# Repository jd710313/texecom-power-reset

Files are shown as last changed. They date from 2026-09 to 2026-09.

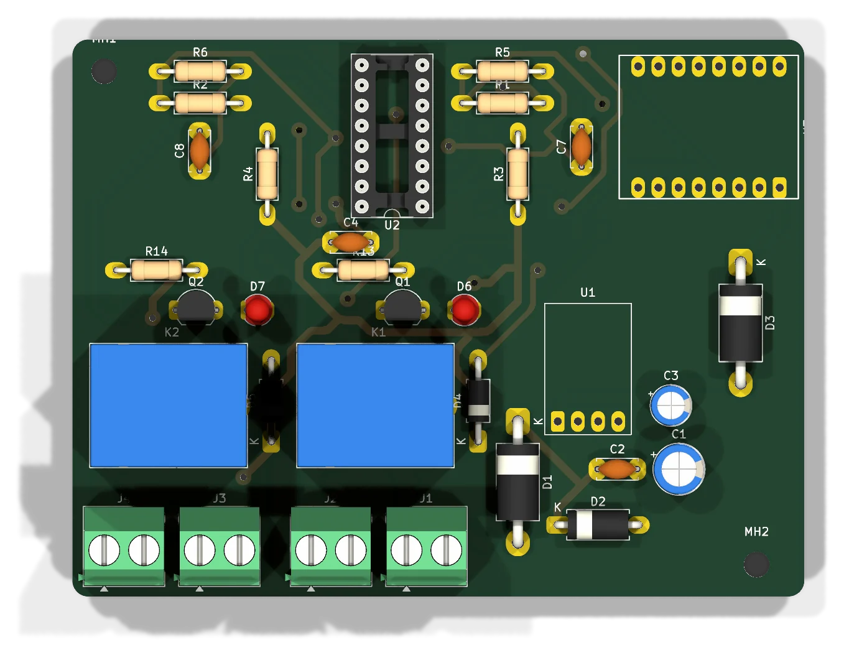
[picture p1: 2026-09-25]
docs/pcb-3d-top.webp

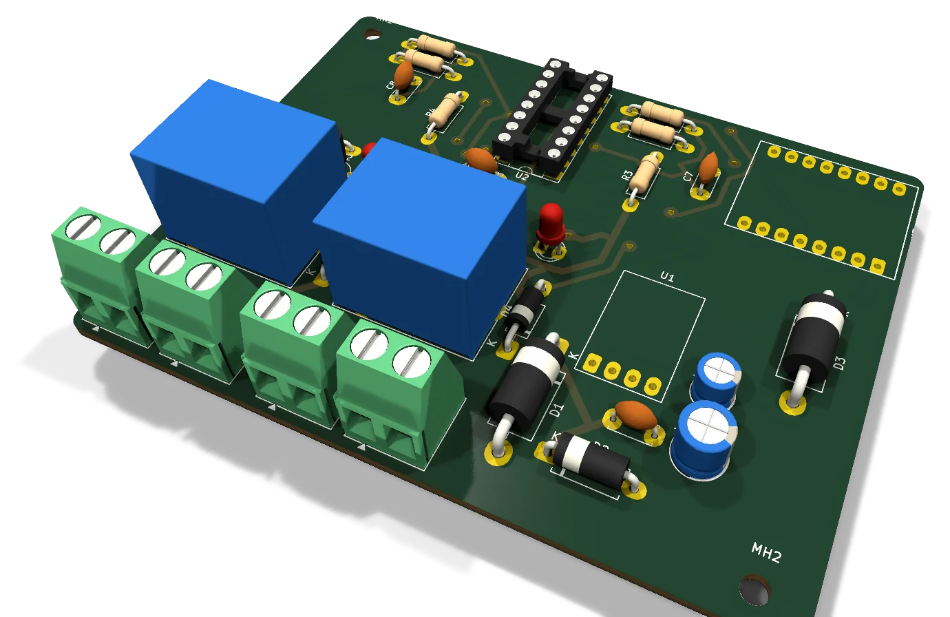
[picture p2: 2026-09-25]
docs/pcb-3d-angled.webp

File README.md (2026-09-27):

# Texecom Remote Power Reset

> **Project summary:** [`project-summary.html`](project-summary.html): one page with the
> reset timing, fail-safe behaviour, schematic, PCB layers, parts and bench tests.
> [View it rendered](https://htmlpreview.github.io/?https://github.com/jd710313/texecom-power-reset/blob/main/project-summary.html)
> (GitHub shows `.html` files as source), or download the file and open it in a browser.

A single board with an ESP32-C3 (Tasmota) and two on-board relays. It sits
inside a Texecom Premier Elite 64-W housing and can remotely "hard power
reset" the panel by briefly cutting both its battery and 16VAC feeds.

> **Status:** Design rev A with **on-board relays**. Schematic done (ERC clean,
> netlist verified). **PCB rev A routed: DRC clean (0 violations, 0 unconnected)**,
> GND pour on the bottom only, with an **engraved top legend** (`Mill_Legend`).
> Gerbers + drill + legend in `fab/`. Not yet milled or tested.

## Background

The panel occasionally raises an **"AUX 12V output failed"** fault. The only
way to clear it is to remove *all* power (battery and AC) and let the panel
restart. This board lets you do that remotely from Home Assistant.

The root cause (probably an overloaded or tripping AUX output) is being
investigated separately. This board is a remote recovery tool, not a fix.

## Requirements

### Panel

| # | Requirement |
|---|---|
| R1 | Panel: **Texecom Premier Elite 64-W** (built-in Ricochet wireless) |
| R2 | Firmware: **V6.05.03LS1** |
| R3 | Panel-side events after a reset (AC/battery fault logs, re-arming, etc.) are **out of scope**. They are handled manually. |
| R4 | AC presence and battery voltage are **already monitored** in Home Assistant through the Texecom integration, so this board doesn't monitor them. |

### Function

| # | Requirement |
|---|---|
| F1 | Remotely perform a "hard power reset" of the panel by cutting both the **battery 12V** feed and the **16VAC** feed at the same time. |
| F2 | Off duration: about **3 seconds** (Tasmota `PulseTime 30`). |
| F3 | Controlled from **Home Assistant over WiFi**, and reachable at all times. |
| F4 | The controller must **stay powered** while both panel feeds are cut. |

### Fail-safe

| # | Requirement |
|---|---|
| S1 | Panel feeds run through the relays' **NC (normally closed)** contacts. Coils are energised only during a reset, so a dead or unpowered board leaves the panel powered. |
| S2 | **Software timeout:** Tasmota `PulseTime`, so the relays release by themselves even if WiFi drops mid-reset. |
| S3 | **Hardware timeout:** a circuit between each GPIO and relay driver limits the maximum on-time (target about 5–10 s). This covers a firmware hang with the GPIO stuck high, and boot-time GPIO glitches. |

### Power

| # | Requirement |
|---|---|
| P1 | Powered from the **12V lead-acid battery only**, about 7.2Ah, tapped *before* the battery relay so it is never switched off. |
| P2 | The whole system is backed by **solar**, so no low-battery cutoff is needed. |
| P3 | Regulator: **Pololu S9V11E2F5** (5V buck-boost, 2–16V in, under 0.2mA quiescent). It supplies 5V to the ESP32-C3 SuperMini (5V pin), the 74HCT4538 and the relay coils. |
| P4 | Regulator input is **16V absolute max**. The battery floats at about 13.7V. The board adds **reverse-polarity protection**, a **bulk input capacitor** (≥33µF; 100µF used) and **transient protection**. |
| P5 | The battery tap on the board gets its **own small fuse** (about 0.5–1A, sized for the board's load). |
| P6 | Low power: Tasmota dynamic `Sleep` (WiFi stays connected). Target about 10–15mA average from the battery. |

### Hardware

| # | Requirement |
|---|---|
| H1 | MCU: **ESP32-C3 SuperMini**, socketed on female headers. |
| H2 | Relays: **2 × Songle SRD-05VDC-SL-C on the main PCB** ([Micro Robotics](https://www.robotics.org.za/SRD-5VDC-SL-C)). 5V coil (about 70mA each), contacts 10A at 30VDC / 250VAC, SPDT. Only COM and NC are used. |
| H3 | Each relay has a **transistor driver** (2N2222A), a **flyback diode** (1N4007) and a **red indicator LED** that lights while the coil is energised. |
| H4 | **Single board:** all field wiring lands on the PCB (battery in, battery out to the panel, 16VAC in, 16VAC out to the panel). There is no board-to-board wiring. |
| H5 | Screw terminals: **KF301-2P** (already on hand). 5.0mm pitch, 16A, 250V, 22–14 AWG, side entry, interlocking. Four are used (J1–J4). |
| H6 | **Custom PCB** (KiCad) holding the SuperMini socket, the S9V11E2F5, the 74HCT4538 hardware timeout, the relay drivers, both relays, the battery input protection and fuse, and J1–J4. |
| H7 | Everything must fit **inside the panel housing**. Rev A board is **92 × 70mm**; the relays are the tallest part (about 15.5mm). |
| H8 | The PCB is **CNC-milled in-house**, **double-sided** (FlatCAM with alignment pins, 30° V-bit with 0.1mm tip, 0.7mm tracks proven), from on-hand copper-clad board. There are **no plated through-holes, no solder mask and no silkscreen**. |

## Parts on hand

| Part | Source | Status in this design |
|---|---|---|
| ESP32-C3 SuperMini | n/a | U3 |
| KF301-2P screw terminals, 5mm (10-pack) | [Micro Robotics](https://www.robotics.org.za/KF301-2P) | J1–J4. **Suitable:** rated 16A / 250V, against about 1.6A max on the battery path and a 16VAC supply. |
| Capacitor kit (CAPKIT) | [Micro Robotics](https://www.robotics.org.za/CAPKIT) | C1 (100µF), C2/C4/C7/C8 (100nF), C3 (10µF) |
| Female and male headers, heat shrink, bootlace ferrules | n/a | SuperMini socket, Pololu header, wiring |
| REL-2CHAN-335V relay module | [Micro Robotics](https://www.robotics.org.za/REL-2CHAN-335V) | **No longer used** (replaced by on-board relays). Kept as a spare and for bench tests. |

## Wiring concept

```
                  ┌─────────────────────────── Main PCB ───────────────────────────┐
Battery +  ──► J1 BAT IN + ──┬──────────────────────────► K1 COM ─┐  NC            │
                             │                                    └──────► J2 BAT OUT + ──► Panel BATT +
                             └─ F1 → D1 → Pololu 5V → ESP32-C3, 74HCT4538, relay coils │
Battery −  ──► J1 BAT IN − ───── GND ─────────────────────────────────► J2 BAT OUT − ──► Panel BATT −
                                                                                       │
16VAC ~A   ──► J3 AC IN ~A ───────────────────────────► K2 COM ─┐  NC                  │
                                                                └──────► J4 AC OUT ~A ──► Panel AC ~A
16VAC ~B   ──► J3 AC IN ~B ───────────────────────────────────────────► J4 AC OUT ~B ──► Panel AC ~B
                  └────────────────────────────────────────────────────────────────┘
```

Each panel power path passes through **only two screw terminals** (in and out)
and one relay contact.

## Panel facts (Texecom INS176-15 installation manual)

From the *Premier Elite 12-W, 24-W & 48/64-W* sections:

| Item | Value |
|---|---|
| Battery fuse | **F6, 1.6A electronic PTC** |
| AUX 12V, Digicom, Network 1, Bell/Strobe fuses | 0.9A electronic PTC each |
| Panel current consumption | 150mA |
| Maximum current available | 1.0A, plus 0.3A battery charge (7Ah setting) |
| **Battery kick-start** | "The panel will only become live when the AC Mains is connected or the Battery Kick-start button is pressed." |
| Power-up order | Connect the battery first, then AC. |
| Troubleshooting | "Remove ALL power (AC Mains and Battery) and then reapply", which is the same procedure this board automates. |

**Relay rating check:** each relay path carries at most about 1.6A (the battery PTC
limit) or the panel's AC input current. The SRD-05VDC-SL-C contacts are rated
10A. **OK.**

**Kick-start consequence:** the panel only restarts after a reset if **AC is
present**. A reset during a real AC outage would leave the panel **off** until
someone presses the kick-start button. The Home Assistant script therefore
checks that AC is present before it resets (see below).

---

## Design: rev A (on-board relays)

### Block diagram

```
 Battery + ─J1─┬─ F1 PTC ─ D1 ─┬─ C1/C2/D2 ─ U1 Pololu ─► +5V ─┬─ D3 ─► SuperMini 5V
               │               │  bulk/TVS                   ├─► U2 74HCT4538 VCC
               │               │                             └─► relay coils, LEDs
               └───────────────┼──────────────► K1 COM ─ NC ─► J2 BAT OUT +
                               │
 GPIO4 ─ R9 1k ─┬─ reset ─┐                                          +5V
                └─ RC ────┴─► U2 ch1 (7 s max) ─ Q ─ R7 1k ─► Q1 2N2222A ─► K1 coil ┤ D4 flyback, D6 LED
 GPIO3 ─ R10 1k ─┬─ reset ─┐                                         +5V
                 └─ RC ────┴─► U2 ch2 (7 s max) ─ Q ─ R8 1k ─► Q2 2N2222A ─► K2 coil ┤ D5 flyback, D7 LED

 J3 AC IN ~A ─► K2 COM ─ NC ─► J4 AC OUT ~A        J3 ~B ─► J4 ~B (straight through)
```

### 1. Power input and protection

| Ref | Part | Purpose |
|-----|---|---|
| J1 | KF301-2P screw terminal | BAT IN (+/−). The power supply taps J1+ on the PCB, **before** the relay path, so it is never switched. |
| F1 | **Resettable PTC fuse**, 1206 SMD, 0.5A hold / 1A trip, 24V (Micro Robotics PTC05A24V) | Protects the board's battery branch (not the panel's battery path). The board draws about 0.25A peak at 12V. After a short, it trips, then resets by itself once the fault is removed. |
| D1 | 1N5822 Schottky (DO-201AD, 3A 40V), in series | Reverse-polarity protection (about 0.3V drop, negligible at about 15mA). |
| C1 | 100µF 35V radial electrolytic | Damps LC spikes from the battery leads, as Pololu recommends for the S9V11 (at least 33µF). |
| C2 | 100nF ceramic (radial, 5.08mm) | High-frequency decoupling. |
| D2 | P6KE18A TVS (DO-15) | Clamps larger transients. Its 15.3V standoff sits above the 13.8V float voltage, so no leakage. It is a last line of protection; C1 is the main LC-spike damper. |
| U1 | **Pololu S9V11E2F5** on a 1×4 header | 5V buck-boost, under 0.2mA quiescent. EN is left open (internal pull-up means always on). |
| C3 | 10µF 50V radial electrolytic | Output decoupling. |
| D3 | 1N5822 Schottky between +5V and SuperMini 5V | **Blocks USB backfeed.** The SuperMini's USB VBUS is tied straight to its 5V pin, so plugging in USB would otherwise push 5V from USB onto the relay coils and the Pololu output. The SuperMini still gets about 4.7V, which is fine for its 3.3V LDO. |

**Current budget (estimated):**

| State | 5V rail | From battery (at 13.6V, about 88% efficiency) |
|---|---|---|
| Idle, WiFi connected, Tasmota `Sleep` | about 25–35mA | **about 11–15mA** (0.3Ah/day, solar-backed) |
| Reset (both relays and LEDs on for 3 s) | about 150mA + ESP | about 90mA for 3 s |
| Worst-case peak (WiFi TX + relays) | about 0.5A | about 0.25A |

### 2. Controller: ESP32-C3 SuperMini

- Plugs into **two 1×8 female headers**, so it can be removed for flashing or
  replacement.
- Relay control pins: **GPIO4 → channel 1 (K1, battery)** and **GPIO3 →
  channel 2 (K2, AC)**. (Swapped from the first draft when the SuperMini
  footprint was corrected; this pairing keeps the tracks from crossing.)
  - Neither is a strapping pin (unlike GPIO2, 8 and 9), nor a USB pin (18, 19)
    or the UART0 pin that prints the boot log (GPIO21).
  - Both are plain inputs with **no internal pull-up at reset** (ESP32-C3
    datasheet, Table 2-1), so they can't pulse a relay while the ESP boots.
    GPIO6 (MTCK) and GPIO9 do have a weak pull-up at reset and are avoided.
- R1 and R2: **100k pull-downs** on the 74HCT4538 side of R9/R10. They hold the
  resets low (relays off) while the ESP is booting, unpowered or removed.
- R9 and R10: **1k series resistors** between each GPIO and the 74HCT4538.
  They protect the ESP when the 5V rail is off. See the note in §3.
- The V2 SuperMini's onboard LED is a **WS2812 RGB LED on GPIO8** (a strapping
  pin). It isn't used as a status LED; leave GPIO8 unassigned in Tasmota.
- **Orientation:** the module mounts **component (button) side up** with its
  **USB-C at the right-hand board edge** (engraved "USB →" on the legend), so it
  can be flashed in place. The antenna end therefore points into the board,
  about 8.5mm above the copper on the header sockets. If WiFi is weak inside the
  panel housing (especially a metal one), use the V2's **IPEX external-antenna
  option** (move the small antenna-select link as described on the module's
  info page) and fit the optional U.FL antenna from the BOM (Micro Robotics
  BAT-P60-WIFI-2, a stick-on flexible PCB antenna on a 100mm lead).

### 3. Hardware timeout: 74HCT4538 dual monostable (at 5V)

One chip (**TI CD74HCT4538E**, DIP-16) covers both channels. Each channel behaves as:

> **relay on = GPIO high AND less than T seconds since the GPIO went high**

| GPIO behaviour | Relay |
|---|---|
| Normal 3 s `PulseTime` pulse | On for 3 s (T is longer, so it never cuts a normal pulse short) |
| GPIO stuck **high** (firmware hang mid-reset) | Released after **T about 5–9 s (7 s nominal)**. It cannot re-trigger without a new low-to-high edge. |
| GPIO low or floating (crash, reboot, ESP removed) | Released immediately, because the reset input R is low |
| Short boot glitch high | Only as long as the glitch (µs), so the relay doesn't respond |
| 5V lost | 74HCT4538, drivers and relay coils all unpowered, relay released |

**Why a 74HCT at 5V (not a 74HC at 3.3V):** it runs from the same 5V rail as the
relay drivers, and it gives a full 5V drive to the transistor bases. HCT inputs
use TTL thresholds (**high = 2.0V or above**, low = 0.8V or below), so the ESP's
3.3V GPIO drives them reliably. (It was chosen originally when bench test 1b
showed the relay *module's* input needed 4.77mA; with on-board relays the choice
still stands.)

**Wiring for each channel.** TI pin names are used here; Nexperia's datasheet
swaps the letters A and B, but the **pin numbers and functions are identical**.

| CD74HCT4538 pin (ch1 / ch2) | Connection |
|---|---|
| R 3 / 13 (active-low reset) | Node N: GPIO through **R9/R10 1k**, with **R1/R2 100k** pull-down to GND at the chip side |
| A 4 / 12 (leading-edge / rising trigger) | Node N through **R5/R6 10k**, with **C7/C8 100nF** to GND. The 1ms delay makes sure reset is released **before** the trigger edge arrives. The Schmitt input handles the slow edge. |
| B 5 / 11 (trailing-edge trigger) | Tied to **VCC** (TI: "an unused B should be tied to VCC") |
| CX 1 / 15 | GND |
| RXCX 2 / 14 | REXT **R3/R4 1M** to +5V. CEXT **C5/C6 10µF X5R 1206** to GND through **R11/R12 100Ω** in series (TI's rapid power-down protection, Fig. 13). |
| Q 6 / 10 | Relay driver: **R7/R8 1k** to the Q1/Q2 base (§3a) |
| Q̅ 7 / 9 | Not used |
| VCC 16 | +5V, with **C4 100nF** decoupling |
| GND 8 | GND |

**Timing:** T = 0.7 × REXT × CEXT = 0.7 × 1M × 10µF ≈ **7 s nominal** (TI
datasheet: τ = 0.7·RX·CX, RX min 5k; noise susceptibility "may occur for
RX > 1M", so 1M is the upper limit). It needs to stay above 3.5 s (the longest
`PulseTime`) and, ideally, below 30 s. **Bench test 3** confirms the real value.
Tune it by lowering REXT or changing CEXT. Keep the RXCX traces short.

- **CEXT must be low-leakage.** With REXT at 1M the timing current is only about
  5µA, so an aluminium electrolytic (leakage in the µA range) would upset the
  timing badly. Use an **X7R/X5R ceramic**. Avoid **Y5V** ceramics, which can
  lose 50–80% of their capacitance.
- **Power-down protection:** TI requires protection when CX is 0.5µF or more.
  The 100Ω in series with CX limits the discharge current into pins 2/14 if 5V
  collapses quickly.
- **Use 74HCT4538** (TI CD74HCT4538E from Communica). A 74HC4538 won't reliably
  read 3.3V inputs at 5V, and a CD4538 has too little output drive.

**ESP protection (does 5V reach the ESP?):** no. The ESP pins only drive the
74HCT4538's **inputs**, which are high-impedance CMOS gates. No 5V output
connects to any ESP pin, so the ESP never sees more than its own 3.3V.

The one corner case is the **5V rail being off while the ESP is powered**, for
example on USB for flashing (D3 blocks USB from the 5V rail). If the ESP then
drives a GPIO high, current could flow through the chip's input clamp diode into
the unpowered 5V rail. **R9/R10 (1k)** limit that to under 3mA, which is harmless
for both parts. They cost nothing in normal operation, because the HCT inputs
draw no current.

### 3a. Relay drivers and relays

| Ref (ch1 / ch2) | Part | Purpose |
|---|---|---|
| R7 / R8 | 1k, 1206 | Base resistor: (5V − 0.75V) / 1k ≈ **4.3mA** base current, within the 74HCT4538's 4mA-class output rating |
| R13 / R14 | 10k, ¼W | Base pull-down: keeps the transistor off if U2 is unpowered or removed from its socket |
| Q1 / Q2 | **2N2222A**, TO-92 | Low-side coil switch. Coil current about 72mA; forced gain about 17, so the transistor is fully saturated. |
| K1 / K2 | **SRD-05VDC-SL-C** | K1 switches the battery (J1 → COM, NC → J2); K2 switches 16VAC ~A (J3 → COM, NC → J4). NO contacts unused. |
| D4 / D5 | **1N4007** | Flyback diode across each coil (cathode to +5V) |
| R15 / R16 + D6 / D7 | 1k, 1206 + **red 3mm LED** | Across each coil: lights (about 3mA) while that relay is energised, that is while the panel feed is **cut** |

**Relay pin-out (KiCad Relay_SPDT_SANYOU_SRD_Series_Form_C, matches the Songle SRD):**
1 = COM, 4 = NC, 3 = NO, 2 and 5 = coil.

**2N2222A pin-out warning:** TO-92 2N2222A parts are usually **E-B-C**, but
some makers use other orders. The footprint is TO-92 inline with pin 1 = E,
2 = B, 3 = C. **Check the pin-out of the actual transistors** before soldering.

**Fail-safe chain:** GPIO low / ESP dead → U2 reset low → Q low → R13/R14 hold
the base low → coil off → **NC closed** → panel powered. U2 unpowered or pulled
from its socket gives the same result.

### 4. Connectors

**Screw terminals:** all **KF301-2P** (5.0mm pitch, 16A / 250V, 22–14 AWG).

| Ref | Label (engraved) | Pin 1 | Pin 2 | Wires to |
|-----|---|---|---|---|
| J1 | BAT IN | + | − | Battery |
| J2 | BAT OUT | + | − | Panel BATT terminals |
| J3 | AC IN | ~A | ~B | 16VAC supply |
| J4 | AC OUT | ~A | ~B | Panel AC terminals |

### 5. Field wiring

| From | To |
|---|-----|
| Battery + / − | J1 BAT IN + / − |
| J2 BAT OUT + / − | Panel BATT + / − (the panel's original battery leads) |
| 16VAC supply ~A / ~B | J3 AC IN ~A / ~B |
| J4 AC OUT ~A / ~B | Panel AC terminals |

**Wire:** 0.5–0.75mm² (20–18 AWG) for the battery and AC runs, with ferrules in
the screw terminals.

**Recommended:** an in-line fuse (about 3A) on the battery + lead, close to
the battery. The battery current now runs through the PCB, and a 7Ah SLA
battery can deliver very high currents into a short before the panel's own F6
PTC (which sits downstream) can do anything.

### 6. PCB

- 2-layer, **about 70 × 50mm** (estimated): two relays (19 × 15.5mm each) in,
  and the relay module, J5, J6, J7 and the control lead out. The housing
  dimensions are still open.
- **Placement:** J1–J4 along one edge with K1/K2 right behind them, so the
  battery and AC paths are short. The SuperMini sits at the opposite edge,
  as far from the relays as possible, with its USB-C at the board edge.
- **Heavy-current traces** (J1 → K1 → J2, J3 → K2 → J4, and the BAT− and AC ~B
  straight-throughs): at least **2mm wide** on 1oz copper (about 3A at
  10°C rise), or copper pours.
- **Clearance:** the 16VAC lines swing about ±23V relative to GND (the
  panel's bridge rectifier references them to 0V). Keep at least 1mm from logic
  traces. This is low voltage, so no mains-level creepage is needed.
- **Footprint pitch:** the KF301 is 5.0mm. Use a 5.0mm footprint (not 5.08mm)
  so that interlocked blocks line up.
- **Through-hole wherever possible:** axial resistors and diodes, radial
  capacitors, TO-92, DIP-16 in a socket, 2.54mm headers. **1206 SMD is
  acceptable** (hand-solderable) and is used for F1, C5/C6 and several resistors.
- GND pour on the **bottom layer only**. The top
  layer carries only tracks, pads and the engraved legend (§6a).
- 2 × M3 mounting holes.

### 6a. CNC-milling rules (H8)

**Process:** KiCad → Gerbers + Excellon drill → **FlatCAM** (isolation and drill
G-code) → CNC. **Double-sided**, with FlatCAM flip alignment using **alignment
pins**. Tool: **30° V-bit, 0.1mm tip**. The machine has milled 0.7mm tracks
reliably (see the example board), and all common drill sizes are available.

Milled boards have **no plated through-holes, no solder mask and no
silkscreen**, so the layout follows these rules:

| Rule | Why |
|---|-----|
| **Double-sided, but a top-layer connection is only allowed on pads that can be soldered on top.** Axial resistors and diodes, and radial capacitors and LEDs mounted slightly raised, can be soldered on top. The IC socket, female headers, male header under the Pololu, relays, TO-92 transistors (usually) and KF301 terminals **cannot**, because their bodies cover the top pads. | There's no plating to carry a top trace to a bottom joint. |
| **Enforced in KiCad:** the footprints of the covered parts get **bottom-copper-only pads**, so neither manual routing nor the autorouter can connect to them on top. | Makes the rule impossible to break by accident, including by the autorouter. |
| **Vias** are drilled and fitted with a **wire link soldered on both sides.** Keep them few (target 10 or fewer), with 0.8mm drill and 2.0mm pads. **0Ω links** (RES-0E-50) can also serve as crossings. | Every via is a manual solder job. |
| **1206 SMD parts go on the bottom side.** | They're soldered on the same side as the through-hole joints. |
| **Traces 0.7mm by default** (proven on this machine; 0.6mm minimum where needed), **clearance at least 0.4mm**. Power paths at least 2mm, and 16VAC traces at least 1mm from logic. | Proven geometry for the 30°/0.1mm V-bit |
| **Oval, oversized pads** (for example 2.0 × 3.0mm for 0.8–1.0mm holes, bigger for terminals, relays and the 1N5822s). | User's standard practice for easy hand soldering |
| **Extra clearance around pads:** a custom KiCad rule of **at least 0.8mm from any pad to other copper** (tracks at 0.4mm to each other), plus **component spacing** that keeps neighbouring pads and bodies well clear. | The user prefers wider isolation around pads for easy hand soldering and no solder bridges. FlatCAM's multi-pass isolation needs room to widen the cut around pads without eating into neighbouring traces. |
| **Drill sizes:** 0.8mm (resistors, small capacitors, LEDs, TO-92, vias), 1.0mm (headers, IC socket, 1N4007, 0Ω links), 1.3–1.5mm (KF301, relay pins, 1N5822 at 1.3mm leads, C1), 3.2mm (M3 mounting holes). | Few tool changes |
| **GND pour on the bottom only.** The top layer has no pour; its unused copper stays as floating copper and carries the engraved legend. | Faster milling and good grounding on the bottom. A top pour would reach pads that can't be soldered on top, and it would leave nowhere to engrave the legend. |
| **SuperMini USB-C at the board edge** (antenna end inward). | Flashing in place, and it let the corrected footprint keep the proven routing. Use the V2's external-antenna option if WiFi is weak. |
| **Legend engraved into the top copper** from the `Mill_Legend` layer (User.1): part outlines, polarity and pin-1 marks, references, the terminal labels BAT IN / BAT OUT / AC IN / AC OUT with + / − on the battery terminals, and a small **ring beside every pad that must be soldered on top** (key: "○ = SOLDER TOP"). The rings are placed so each one is clearly nearest its own pad. Generated so every line stays **at least 0.35mm clear of any top copper feature or hole** (plus half the line width), so an engrave can never cut a track or pad. | No silkscreen. The legend shows where each part goes. |
| After testing, **coat the board** (conformal coat or clear lacquer). | No solder mask, and the board lives in the panel for years. |

**Routing:** I place the parts and then try routing. If that's poor, use the
user's preferred autorouter, the **KiCad routing tools (Go implementation)**, with
the rules above as design rules.

### 6b. KiCad project

| File | Contents |
|---|---|
| `texecom-power-reset.kicad_pro` / `.kicad_sch` | Project and schematic (A3, single sheet). **Drawn with wires**; only GND, +5V and +5V_MCU use power symbols or labels. |
| `texecom-power-reset-schematic.pdf` | Schematic PDF export |
| `texecom-power-reset.kicad_sym` | Project symbols: ESP32-C3-SuperMini (from the esp32c3-button-led project), Pololu_S9V11E2F5 |
| `texecom-power-reset.pretty/` | Project footprints: ESP32-C3-SuperMini (**pin rows corrected 2026-09-25**: the first version was mirrored, which would have put 5V and GND on GPIO5/GPIO6 with the module button side up), Pololu_S9V11E2x (pin order VOUT, GND, VIN, EN per the Pololu drawing) |
| `backup/` | Earlier schematic versions (label-connected, and wired with the off-board relay module), kept for reference only. **Not** used for the PCB. |
| `project-summary.html` | One-page visual project summary (self-contained HTML, open in a browser) |
| `fab/` | **Reference export** (maintained with the design): Gerbers F.Cu / B.Cu / Edge.Cuts / Mill_Legend, Excellon drill, drill map |
| `kicad-output/` | Working KiCad output folder used for milling (Gerbers, drill and anything else needed) |
| `flatcam/` | FlatCAM work: project files and generated G-code |
| `docs/` | Copper renders (top includes the legend), 3D renders, and the **top and bottom assembly drawings** (`pcb-assembly-top` / `pcb-assembly-bottom`, SVG + PDF) |
| `tools/make_legend.py` | Regenerates the `Mill_Legend` engrave layer, kept clear of all top copper |
| `tools/make_assembly.py` | Regenerates the top and bottom assembly drawings (SVG + PDF) from the board |

**Layout:** power path across the top. **Channel 2** (GPIO3, K2 AC relay) is in
the middle band and **channel 1** (GPIO4, K1 battery relay) in the lower band.
This order avoids wire crossings from the SuperMini. J3/J4 (AC) sit next to K2,
and J2 (BAT OUT) next to K1. The BAT_IN+ wire runs from J1 over the top and down
the right side to K1 COM.

**Reference designators** match BOM.md: U1 Pololu, U2 74HCT4538 (units A/B =
channels 1/2, unit C = power), U3 SuperMini, J1–J4 KF301 terminals, K1/K2
relays, Q1/Q2 2N2222A, F1 PTC, D1/D3 1N5822, D2 P6KE18A, D4/D5 1N4007,
D6/D7 LEDs, C1–C8, R1–R16, MH1/MH2 M3 holes.

**Verification:** ERC 0 errors, 0 warnings. The KiCad netlist was checked net
by net against the intended circuit (32 nets). The only unconnected pins are the
intentional ones (relay NO, Q̅ outputs, Pololu EN, unused SuperMini pins).

### 6c. PCB layout (rev A)

Top copper
Bottom copper

| Item | Value |
|---|---|
| Board | **92 × 70mm**, 2 layers, 2 × M3 holes (top-left, bottom-right) |
| Placement | Terminals along the bottom edge: **J4 AC OUT, J3 AC IN, J2 BAT OUT, J1 BAT IN** (left to right). K2 (AC) above J4/J3, K1 (battery) above J2/J1. Drivers and LEDs above the relays, 74HCT4538 top-middle, SuperMini top-right (button side up, **USB-C at the right-hand edge**, antenna end pointing inward), power section bottom-right. |
| Routing | KiCad routing tools (drandyhaas), with a milling floor: **0.8mm clearance** everywhere (1.0mm for 16VAC), 0.7mm signal tracks, 1.0mm supply tracks, 2.0mm battery/AC tracks. GND by a **bottom-layer pour only**, plus a few GND tracks. |
| Vias | **16 wire-link vias** (0.8mm drill, 2.0mm pad): solder a short wire on both sides. |
| Legend | `Mill_Legend` layer (User.1), engraved into the top copper with the V-bit. See *Engraving the legend* below. |
| DRC | **0 violations, 0 unconnected** against the project rules (`.kicad_pro` net classes + `.kicad_dru`). |
| Fab files | `fab/`: `texecom-power-reset-F_Cu.gbr`, `-B_Cu.gbr`, `-Edge_Cuts.gbr`, `-Mill_Legend.gbr` (legend engrave), `texecom-power-reset.drl` (Excellon, mm, absolute origin; PTH and NPTH merged), drill map PDF. |

**Drill sizes:**

| Drill | Holes | Used for |
|---|---|---|
| 0.8mm | 66 | Resistors, disc caps, electrolytics, TO-92, DIP socket, the 16 vias |
| 0.9mm | 4 | LEDs |
| 1.0mm | 30 | SuperMini and Pololu headers, 1N4007/P6KE18A, relay coil pins |
| 1.3mm | 14 | KF301 terminals, relay contact pins |
| 1.5mm | 4 | 1N5822 (1.3mm leads) |
| 3.2mm | 2 | M3 mounting holes |

**How the "no top joint on covered pads" rule is enforced** (so the router can't
create a connection that can't be soldered):

- KiCad forces plated pads onto both copper layers, so the covered footprints
  (terminals, relays, DIP socket, headers, TO-92, electrolytics, LEDs) carry a
  **per-pad F.Cu keepout** (no tracks, no vias, no pour) inside the footprint.
  These are in the `*_Mill` footprints in `texecom-power-reset.pretty/`.
- There is **no top pour** at all. The `.kicad_dru` rule **"no top pour on
  covered pads"** (`zone_connection none` on F.Cu) is kept as a guard in case a
  top pour is ever added again. DRC connectivity is therefore honest: every
  connection it counts is solderable.

**Assembly notes for the milled board:**

Two assembly drawings, both printable at 2:1 on A4 landscape (print at 100%).
The vias carry the same numbers on both.

- **Top side** ([PDF](docs/pcb-assembly-top.pdf)): every top-side part with
  its reference and value, its outline with polarity and pin-1 marks, and the
  20 pads that need a top solder joint ringed in orange (the same pads as the
  rings on the engraved legend).
- **Bottom side** ([PDF](docs/pcb-assembly-bottom.pdf)): there's no silkscreen
  on the bottom, so this shows the board as seen from below (mirrored), with the
  eleven 1206 parts labelled and all 16 vias numbered. The through-hole parts
  appear in grey for orientation.

Top-side assembly drawing

Bottom-side assembly drawing

1. **Vias:** fit a wire through each of the 16 vias and solder both sides first.
2. **SMD (1206) parts are on the bottom** (F1, C5, C6, R7–R12, R15, R16): solder
   them first, on the bottom.
3. **Axial parts and disc capacitors** (R1–R6, R13, R14, D1–D5, C2, C4, C7, C8):
   mount them **1–2mm off the board** so the iron can reach the top pads, and
   **solder every pad on both sides**. The holes aren't plated, so the top and
   bottom pads are only joined by solder on the lead. Twenty of these pads carry
   a top track, and for those the top joint is **essential** (some have no
   bottom track at all). They're marked on the board with a small engraved
   **ring (○ = SOLDER TOP)** next to the pad. Soldering the other top pads is
   harmless and keeps the rule simple.

   | Part | Type | Pads with a top track | Net |
   |------|------|-----------------------|-----|
   | R1 | Axial resistor | 1, 2 | U2A reset, GND |
   | R2 | Axial resistor | 1 | U2B reset |
   | R3 | Axial resistor | 1 | +5V |
   | R4 | Axial resistor | 1 | +5V |
   | R5 | Axial resistor | 1, 2 | U2A reset, U2A trigger |
   | R6 | Axial resistor | 1, 2 | U2B reset, U2B trigger |
   | R13 | Axial resistor | none | |
   | R14 | Axial resistor | 2 | GND |
   | D1 | Axial diode (1N5822) | 1 | D1 cathode |
   | D2 | Axial diode (P6KE18A) | 1 | D1 cathode |
   | D3 | Axial diode (1N5822) | none | |
   | D4 | Axial diode (1N4007) | 1, 2 | +5V, D4 anode |
   | D5 | Axial diode (1N4007) | 1 | +5V |
   | C2 | Disc capacitor | 1 | D1 cathode |
   | C4 | Disc capacitor | 1, 2 | +5V, GND |
   | C7 | Disc capacitor | 1 | U2A trigger |
   | C8 | Disc capacitor | 1 | U2B trigger |

   Solder the top joint first, then the bottom. Afterwards, check continuity
   from each ringed pad to the far end of its top track.
4. **Everything else** (terminals, relays, socket, headers, TO-92s, electrolytics,
   LEDs) is soldered on the **bottom only**; their top pads are isolated rings.
   - **SuperMini (U3):** solder male pins to the module and two 1×8 female
     headers to the board (bottom side). Plug the module in **button side up,
     USB-C towards the right-hand board edge**, following the engraved
     "USB →" arrow. Before plugging it in, check that the square pad (pin 1,
     5V) is at the USB end of the row nearest the relays.
5. After testing, coat the board (no solder mask).

**Milling order (double-sided, alignment pins, height map):**

1. **Alignment-pin holes** first, outside the board outline, so the pins are
   ready for the flip.
2. **Bottom side:** probe a height map (no holes yet, so the probe can't drop
   into one), then mill the **B.Cu isolation, mirrored** around the pin axis
   (**4 passes**, see *Isolation passes* below).
3. **Flip** onto the alignment pins and probe a **new height map on the top**
   (the top face isn't flat in the same way as the bottom).
4. **Top isolation** (F.Cu, not mirrored, **4 passes**).
5. **Legend** (Mill_Legend, not mirrored) with the same V-bit, Z zero and
   height map; see below.
6. **Drill from the top** (drill file not mirrored), with a firm sacrificial
   backing so exit burrs on the bottom pads stay small. Re-zero Z after each
   drill change (the height map isn't needed for drilling through). Mill the
   3.2mm M3 holes as circles if you don't have a 3.2mm drill.
7. **Board outline last** (2.4mm tool, 4 passes to −2.0mm, no tabs). The board
   is held on **double-sided tape**, so it stays put after the final pass; tape
   near the edges as well as the middle. The drills go through the tape, so
   clean adhesive off the small bits if holes start to come out ragged.
8. Lightly deburr the bottom pads before soldering.

**Isolation passes (copper layers): use 4, not 1**

The first board was milled with **one pass** of the V-bit (about 0.14mm wide at
−0.07mm). Isolation routing cuts a line **around the outline** of each copper
shape; it doesn't clear the space *between* shapes. With one pass:

- **Top:** there's no pour, so every pad and track sits in unused, floating
  copper only about 0.14mm away. Solder can bridge a pad to that copper, and if
  the same piece touches another pad, you get a short.
- **Bottom:** the Gerber has 0.8mm gaps between tracks, pads and the GND pour.
  One pass traces *both edges* of each gap: narrow gaps get cleared completely
  (the cuts merge), wider or irregular ones (for example around thermal-relief
  spokes) keep a **sliver of copper** between the two cuts. That's why the
  separation looked wide in some places and thin in others.

Settings for both copper layers (FlatCAM Beta, Isolation tool):

| Setting | Value |
|---|---|
| Passes | **4** |
| Overlap | **15–20%** |
| Combine | On (all passes in one job) |
| Tool, depth, height map | Unchanged (30° V-bit, 0.1mm tip, −0.07mm, auto-level) |

That gives about 0.45–0.5mm of isolation from every copper edge: the 0.8mm
bottom gaps are cleared completely (no slivers, even look), and the top pads get
about 0.5mm to the floating copper. The **legend stays a single Follow pass**.
FlatCAM's Non-Copper Clearing would remove all unused copper, but with a 0.1mm
V-bit it's very slow; the extra passes give the clearance that matters.

**Checking a milled board:** under magnification, scrape out any copper slivers
with a sharp hobby knife and brush the dust away. Then check with a continuity
meter for shorts between neighbouring pads, and from each pad to the copper
around it, especially the terminal, relay and 5V pads, before soldering.

**Alignment holes with a 2.4mm fishtail end mill (at 12,000rpm):**

| Setting | Value | Why |
|---|---|---|
| Z (plunge) feed | **100–150mm/min** (no more than about 200) | About 0.0125mm/rev, or 0.006mm per flute on a 2-flute bit: enough to cut chips in FR4. The earlier 60mm/min tends to rub, which heats the resin, glazes the hole and dulls the bit. A fishtail isn't a drill (no point, no self-centring), and hobby machines flex under heavier plunges. |
| Step-down | **1mm per step**, full retract between steps (−1, −2, −3mm) | Clears the fibreglass dust; 3mm total is a 1.6mm board plus about 1.4mm into the spoilboard for the pins. |
| Dust | Vacuum while drilling | Fibreglass dust packs into the flutes. |

- **Pin fit:** a flat-bottomed end-mill hole comes out very close to the bit
  size. If the pins are also 2.4mm, test on scrap first. If they're too tight,
  use a slightly smaller pin, or mill the holes (FlatCAM "mill holes") for a snug
  sliding fit.
- **First hole:** if the bit squeals or the resin turns brown, increase the feed
  a little rather than slowing down.
- These are general carbide-in-FR4 figures for hobby spindles; if the bit's
  supplier lists feeds, use those.

**Hole drills at 12,000rpm (carbide PCB drills in FR4):**

| Drill | Holes | Z (plunge) feed |
|---|---|---|
| 0.8mm | 66 | **60–90mm/min** |
| 1.0mm (includes the 0.9mm LED holes) | 34 | **80–120mm/min** |
| 1.5mm (includes the 1.3mm terminal and relay-contact holes) | 18 | **100–150mm/min** |
| 3.2mm (M3) | 2 | **120–180mm/min** |

- PCB drills are designed for 30,000–100,000rpm. At 12,000rpm each turn must
  take a smaller bite, or thin bits break, so the feed scales with the diameter
  (about 0.005–0.015mm per revolution).
- A single plunge to −2.0mm (no pecking) is fine for a 1.6mm board at these
  sizes. Set **Feedrate Z per tool** in FlatCAM's drilling job and regenerate the
  drill G-code.
- The **0.8mm bit is the fragile one**: keep it at the low end, make sure it
  runs true, and clean tape adhesive off it. On the larger bits, if a bit
  squeals or the hole edges go brown, raise the feed a step rather than slowing
  down.
- These are general figures for hobby spindles; if the drill supplier lists
  feeds, use those.

**Engraving the legend (FlatCAM):**

The legend Gerber is made of 0.15mm-wide lines. Normal isolation routing would
cut *around* each line (a double outline); **Follow** geometry runs the tool
once down the **centre** of each line, so the V-bit cuts a single thin groove.

1. Load `fab/texecom-power-reset-Mill_Legend.gbr` together with the F.Cu
   Gerber. It shares their origin, so it lines up with the top isolation and
   the alignment pins. Apply **exactly the same** offset or double-sided
   move/mirror to the legend as to F.Cu (select both and apply it once).
2. Make the Follow geometry:
   - **FlatCAM Beta (8.99x):** select the legend Gerber, open the **Isolation
     Routing** tool and tick **Follow**. Tool diameter and passes don't matter
     with Follow. Generate: this creates a `…_follow` geometry.
   - **FlatCAM 8.5:** select the legend Gerber; in the Selected tab under
     *Isolation Routing* tick **Follow**, then *Generate Geometry*.
   - Check the result: text, outlines and rings should be single centre
     lines, not pairs of outlines.
3. CNC job on the follow geometry: tool type **V-shape, 0.1mm tip, 30°**,
   **Cut Z about −0.05 to −0.07mm** (just through 35µm copper, giving a line
   about 0.12–0.14mm wide), **multi-depth off**. Use the feeds, speed and
   travel Z from the top isolation job. A deeper cut widens the lines and blurs
   the small text (1.2mm references, 1.5mm terminal labels), so try a short
   test on scrap first.
4. The cut is very shallow, so **use the top height map** (auto-levelling);
   without it, lines fade out on high spots and cut wide on low ones.
5. The legend was generated at least 0.35mm clear of everything on the top
   copper, so even a slightly deep cut only marks floating (unconnected) copper.
   If you change the layout, regenerate it with `tools/make_legend.py` (run with
   KiCad's Python; see the script header) rather than editing it by hand.

FlatCAM menu names differ a little between versions.

### 7. Tasmota configuration

Build: `tasmota32c3.bin` (flash through the SuperMini's USB-C, with the board
unpowered from the battery; D3 isolates USB from the relay rail).

`Configuration → Configure Module` (Generic ESP32-C3):

| GPIO | Function |
|---|---|
| GPIO4 | Relay 1 (battery, K1) |
| GPIO3 | Relay 2 (AC, K2) |
| GPIO8 | None (WS2812 RGB LED and strapping pin; leave unassigned) |

Console:

```
Backlog PowerOnState 0; PulseTime1 30; PulseTime2 35; Sleep 100; FriendlyName1 Panel Battery Cut; FriendlyName2 Panel AC Cut
```

| Setting | Why |
|---|-----|
| `PowerOnState 0` | Relays are **always off** after an ESP reboot or power-up. |
| `PulseTime1 30` | Battery cut for 3.0 s. |
| `PulseTime2 35` | AC cut for 3.5 s. Battery comes back first, then AC, which matches the manual's power-up order. The panel goes live when AC returns. |
| `Sleep 100` | Dynamic sleep for lower average current while WiFi stays connected. |

If the SuperMini has trouble holding a WiFi connection (a known issue with some
SuperMini antenna layouts), try `WifiPower 8.5`. On this board the antenna end
points inward over the PCB, so if the signal inside the panel housing is poor,
switch the V2 to its IPEX external antenna.

### 8. Home Assistant script (example)

Entity IDs are placeholders. Adjust them, and the AC-OK condition, to match the
Tasmota and Texecom integrations.

```yaml
script:
  texecom_hard_power_reset:
    alias: "Texecom hard power reset"
    mode: single
    sequence:
      # Never reset without AC: the panel would not restart without the kick-start button.
      - condition: state
        entity_id: binary_sensor.texecom_ac_ok        # placeholder
        state: "on"
      - action: switch.turn_on
        target:
          entity_id:
            - switch.texecom_reset_panel_battery_cut   # placeholder
            - switch.texecom_reset_panel_ac_cut        # placeholder
```

### 9. Bench tests before installing

Do these with a bench supply of about 12–13.8V on J1, **before** connecting
the panel.

1. **Power-up:** the +5V rail reads 4.9–5.2V, both LEDs stay **off**, and both
   relays stay released. The NC contacts show continuity: J1+ to J2+, and
   J3 ~A to J4 ~A.
2. **Normal pulse:** turn on `Power1`. K1 clicks, D6 lights, and J1+ to J2+ opens
   for 3.0 s, then everything releases. Repeat with `Power2` (K2, D7, 3.5 s).
3. **Hardware timeout:** set `PulseTime1 0` (no software timeout) and turn on
   `Power1`, so the GPIO stays high. K1 should release after about 5–9 s
   (7 s nominal) and stay off. Afterwards, restore `PulseTime1 30`. Repeat for
   channel 2.
4. **Fail-safe:** unplug the SuperMini, and separately pull U2 from its
   socket. Both relays must stay released (NC closed) and the LEDs off.
5. **USB isolation:** with J1 disconnected, plug in USB. The relays, LEDs and
   +5V rail must **not** power up.
6. **Idle current:** measure the J1 current with WiFi connected. The
   target is about 15mA or less.

### Bill of materials

The full BOM and sourcing tracker (on hand / Micro Robotics / Communica) is in
**[BOM.md](BOM.md)**.

## Commercial alternative: ESP8266 2 × 30A relay board

If milling the custom board isn't worth it, Micro Robotics'
[ESP8266-2CH-30A](https://www.robotics.org.za/ESP8266-2CH-30A) (R236, 83 × 68mm)
can do the same job with the same wiring (checked against its
[schematic](https://github.com/microrobotics/ESP8266-2CH-30A/blob/main/Schematic_ESP8266-2CH-30A.jpg)):

- **Wiring:** battery + through relay 1 (COM → **NC**), one AC line through
  relay 2 (COM → **NC**); battery − and the other AC line straight to the
  panel. Power the board (7–28V input, LM2596 5V buck) from the battery side
  of relay 1's COM, through the **inline blade fuse** from the BOM, so it's
  never switched off with the panel.
- **Fail-safe:** each relay has an NPN driver with a 1k base resistor and a
  **10k pull-down**, plus a flyback diode and LED. If the ESP crashes, reboots or
  is removed, the relays drop out and the panel keeps its power.
- **Move relay 1 off GPIO16.** The relays reach the ESP through links on header
  P5 (Relay 1 ↔ GPIO16, Relay 2 ↔ GPIO14). GPIO16 goes high briefly at boot,
  which could blip the battery relay on every ESP restart, so wire Relay 1 to
  **GPIO12 or GPIO13** instead (both brought out on P5, no boot glitch).
- **Tasmota** (`tasmota.bin`, Generic module): Relay1 = GPIO12 (or 13),
  Relay2 = GPIO14, Button1 = GPIO0, LedLink_i = GPIO5 (blue LED; check the
  polarity). Use the same `PowerOnState 0; PulseTime1 30; PulseTime2 35`.
  Flash through the UART header with a 3.3V USB-TTL adapter (IO0 to GND while
  flashing); later updates go over the air.

**What it gives up compared with the custom board:**

| | Custom board | ESP8266-2CH-30A |
|---|---|---|
| Hardware timeout (S3) | 74HCT4538 releases the relays after about 7 s even if the firmware hangs with a GPIO high | None. Relies on `PulseTime` and the ESP8266 watchdog (a reset floats the pins and the pull-downs release the relays). A firmware bug that keeps the pin high while the chip keeps running isn't covered. |
| Idle current from the battery | about 11–15mA | about 25–40mA (ESP8266 plus a non-synchronous buck); fine with solar backing |
| Flashing | USB-C, in place | UART header and USB-TTL adapter; OTA afterwards |
| Antenna | Ceramic, plus the V2's IPEX external-antenna option | ESP-12F PCB antenna only (could be weak inside a metal housing) |
| Build effort | Mill, drill and assemble | Buy, move one link, wire up |

Verdict: a sound substitute, especially with relay 1 moved to GPIO12/13. The
custom board is kept for the hardware timeout, lower idle current, USB-C
flashing and the external-antenna option.

## Open items

- [ ] Free space inside the 64-W housing (dimensions still to come), including height for the relays (about 15.5mm)
- [x] ~~Panel fuse ratings~~: the battery fuse is 1.6A PTC, which is well within the 10A relay rating
- [x] ~~Relay module trigger polarity and 3.3V drive (tests 1a/1b)~~: done 2026-09-25 (high-level trigger, 4.77mA at 3.3V). No longer relevant, because the module was replaced by on-board relays.
- [x] ~~KiCad schematic~~: done with on-board relays, drawn with wires, ERC clean, netlist verified (2026-09-25)
- [ ] Check the pin-out of the 2N2222A transistors actually bought (E-B-C expected)
- [x] ~~PCB layout~~: rev A placed and routed, DRC clean, Gerbers and drill in `fab/` (2026-09-25)
- [ ] Mill, assemble and bench-test rev A (section 9)

## Decisions log

| Decision | Reason |
|---|---|
| Pololu S9V11E2F5 instead of the XL7015 | The XL7015 (5–80V, 150kHz, non-synchronous) is inefficient at light load and bulky. The S9V11E2F5 has under 0.2mA quiescent current, a light-load mode, and a 10.9 × 16.5mm footprint. |
| Battery-only supply (no 16VAC diode-OR) | Rectified 16VAC peaks at about 22–25V, above the S9V11E2F5's 16V max. Solar backing makes battery drain a non-issue. |
| No low-battery cutoff | The system is solar-backed. |
| No AC or battery monitoring on the board | Already provided by the Texecom integration in HA. |
| KF301-2P terminals (on hand) | Rated 16A / 250V and accepts up to 14 AWG, well above the 1.6A battery path and 16VAC. |
| Hardware timeout in addition to `PulseTime` | `PulseTime` is software and can't release a relay if the firmware hangs with the GPIO high. |
| 4538 monostable for the hardware timeout | One chip covers both channels. Its precise timing (0.7·R·C) beats a MOSFET-threshold RC, and its reset input gives "GPIO AND timer" logic without extra gates. |
| Battery restores 0.5 s before AC (`PulseTime1 30` / `PulseTime2 35`) | Matches the manual's power-up order (battery first, then AC). |
| HA script requires AC present | Without AC the panel won't restart unless the kick-start button is pressed. |
| D3 Schottky diode in the SuperMini 5V feed | The SuperMini's USB VBUS connects straight to its 5V pin. The diode stops USB from backfeeding the relay rail and regulator. |
| Through-hole parts wherever possible; 1206 SMD acceptable | User preference. 1206 is large enough to hand-solder. |
| F1 = PTC05A24V (1206, 0.5A hold) instead of the radial WDS250-500 (0.25A hold) | More margin over the peak load, and it's in stock at Micro Robotics. |
| CEXT 10µF X5R 1206 with REXT 1M | 22µF through-hole ceramics are hard to find. 10µF with 1M gives T ≈ 7 s. |
| 1N5822 for D1/D3 | Micro Robotics stocks the 1N5822, not the 1N5819. |
| Parts sourced from Micro Robotics (robotics.org.za) where possible | User preference. Tracked in BOM.md. The 74HCT4538 and the P6KE18A come from Communica. |
| **74HCT4538E at 5V** instead of 74HC4538 at 3.3V | Bench test 1b measured 4.77mA per relay-module input at 3.3V, too close to a 3.3V 74HC's drive limit. At 5V the HCT has margin, and its TTL input levels still accept 3.3V from the ESP. It also suits the on-board transistor drivers. |
| 1k series resistors (R9/R10) between the GPIOs and the 74HCT4538 | They limit the clamp-diode current if the ESP drives a GPIO high while the 5V rail is off (USB-only power). |
| 100Ω in series with CEXT (R11/R12) | TI's recommended rapid power-down protection for CX of 0.5µF or more, without adding diode leakage across the 1M timing resistor. |
| Kept the Pololu S9V11E2F5 over the on-hand XL4015 and MP4560 modules | XL4015: too large (54 × 23 × 18mm), high idle current, trimpot output. MP4560: acceptable (55V input, pulse skipping), but its trimpot output could drift and over-voltage the ESP, 74HCT4538 and relays. The Pololu has a fixed 5V output and under 0.2mA idle current. |
| Schematic drawn with wires (not only net labels) | Readability. Only GND, +5V and +5V_MCU use power symbols or labels. |
| **On-board SRD-05VDC-SL-C relays instead of the REL-2CHAN-335V module** | Each panel power path drops from 4 screw terminals plus 2 wires to **2 terminals**. A loose connection there would silently cut the panel's battery or AC. It also removes the inter-board wiring, the crimped control lead, J5–J7, the Q/Q̅ links and R7/R8 (220Ω). The cost is a board about 70 × 50mm and a few cheap driver parts. |
| 2N2222A + 1k base + 10k pull-down + 1N4007 flyback per relay | Standard low-side driver, all in stock at Micro Robotics. The pull-down keeps the relay off if U2 is unpowered or removed. |
| Red LED + 1k across each coil | Shows at a glance which feed is being cut (it replaces the module's indicator LEDs) and helps with bench testing. |
| Per-pad F.Cu keepouts in the covered footprints (not NPTH + bottom SMD pads) | KiCad forces plated pads onto both layers. Modelling the pads as NPTH + B.Cu SMD made the router treat each hole as an obstacle to its own pad. Keepouts inside the footprints block top tracks, vias and pour at those pads, travel with the part, and the router honours them. |
| 0.8mm clearance on every net class (not just around pads) | Wide isolation for easy hand soldering and FlatCAM multi-pass isolation. The board is not dense enough to need less. |
| ~~GND by pour on both layers~~ (superseded below), plus a `zone_connection none` rule on F.Cu for covered pads | Keeps DRC connectivity honest for a board without plated holes. |
| **GND pour on the bottom only; the top copper carries an engraved legend** (2026-09-25) | The top pour added little: GND is well connected on the bottom, and three pads needed only short re-routes (one extra via). Without it, the free top copper can take a V-bit legend (outlines, references, BAT/AC terminal labels) to guide assembly. The legend is pre-clipped 0.35mm clear of all top copper, so it can't cut a track or pad. |
| **SuperMini footprint corrected and rotated 180°; GPIO4 = channel 1, GPIO3 = channel 2** (2026-09-25) | The first footprint had its pin rows mirrored (it matched the module's bottom-view pinout drawing), so the module would only have fitted button side down. With the rows corrected, rotating the module 180° puts GPIO4/GPIO3 exactly on the old IO pads and 5V/GND next to D3 and the main GND pour, so the proven routing stays (DRC clean, still 16 vias). Keeping the antenna at the edge instead would have put 5V and GND against the board edge and split the GND pour. The trade-off is the antenna end pointing inward; the V2's IPEX external-antenna option covers weak WiFi. GPIO3 and GPIO4 have no pull-up at reset. |

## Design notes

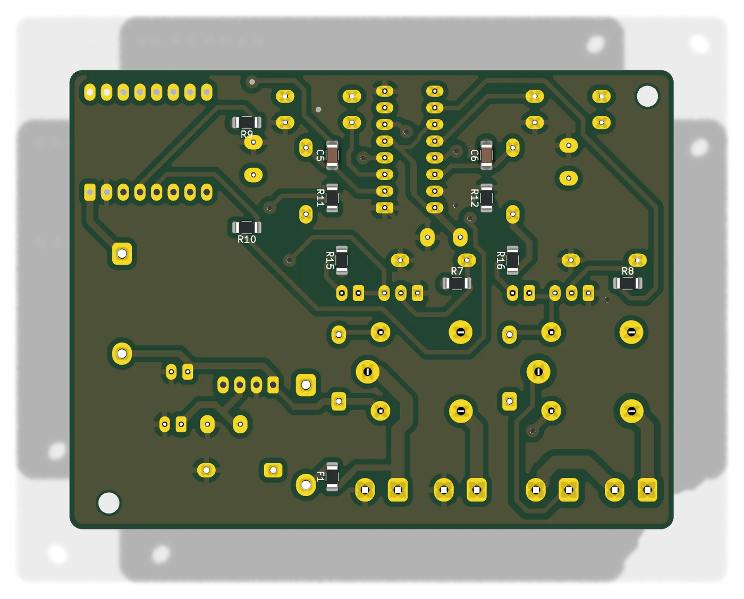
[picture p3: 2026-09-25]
docs/pcb-3d-bottom.webp

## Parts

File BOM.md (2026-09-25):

# BOM and Sourcing Tracker: Texecom Remote Power Reset

Single board with on-board relays. Through-hole wherever possible; **1206 SMD is
acceptable**. Preferred supplier: **Micro Robotics**
([robotics.org.za](https://www.robotics.org.za)). Anything they don't carry comes
from **Communica** ([communica.co.za](https://www.communica.co.za)).

**Source column:** **On hand** (already have it) · **Micro Robotics** · **Communica**. The **Stock** column shows Micro Robotics or Communica availability at the time of checking.

> Stock was checked on **2026-09-25** on the Micro Robotics product pages
> (Centurion / Stellenbosch) and on Communica's site. Stock changes, so
> re-check before ordering. Communica's "available" flag is from their web
> shop. Their note says stock is held at the Samrand branch only.

## Main PCB

| Ref | Qty | Part | Source | Code | Pack / price | Stock (Centurion / Stellenbosch) | Notes |
|-----|-----|---|---|---|---|---|---|
| U1 | 1 | Pololu S9V11E2F5 5V buck-boost | **Micro Robotics** | [5713](https://www.robotics.org.za/5713) | 1 / R80 | In stock / Limited | |
| U2 | 1 | **74HCT4538E** (TI CD74HCT4538E) dual monostable, DIP-16, runs from **5V** | **Communica** | [74HCT4538E](https://www.communica.co.za/products/74hct4538e) | 1 / R7.38 | Available | **Not carried by Micro Robotics.** Must be **HCT** (TTL inputs accept the ESP's 3.3V). Not 74HC4538, not CD4538. Consider buying 2 (one spare). |
| U2 socket | 1 | IC socket 16-pin | **Micro Robotics** | [IC-SOC-16P](https://www.robotics.org.za/IC-SOC-16P) | 4 / R7 | In stock / In stock | |
| U3 | 1 | ESP32-C3 SuperMini | **On hand** | n/a | n/a | n/a | |
| H1 | 2 | Female header 1×8, 2.54mm (SuperMini socket) | **On hand** | [HFST-08-TH254](https://www.robotics.org.za/HFST-08-TH254) | 10 / R12 | In stock / In stock | Needs two 1×8 female strips (or longer strips cut down; cutting a female header costs one position). |
| H2 | 1 | Male header, 2.54mm (1×4 for U1, cut from a 40-way strip) | **On hand** | [HMST-40-TH254](https://www.robotics.org.za/HMST-40-TH254) | 10 / R16 | In stock / In stock | Pololu doesn't include header pins. |
| J1–J4 | 4 | KF301-2P screw terminal, 5.0mm | **On hand** | [KF301-2P](https://www.robotics.org.za/KF301-2P) | 10 / R14 | In stock / In stock | 10-pack on hand (4 used) |
| K1, K2 | 2 | **Relay SRD-05VDC-SL-C**, 5V coil, SPDT 10A | **Micro Robotics** | [SRD-05VDC-SL-C](https://www.robotics.org.za/SRD-5VDC-SL-C) | 4 / R30 | In stock / In stock | Songle original. 2 spares in the pack. |
| Q1, Q2 | 2 | **2N2222A** NPN, TO-92 | **Micro Robotics** | [2N2222A-TO-92](https://www.robotics.org.za/2N2222A-TO-92) | 4 / R12 | In stock / In stock | **Check the pin-out** before soldering (usually E-B-C). [BC547](https://www.robotics.org.za/BC547) (100mA, in stock) is an alternative; its pin-out is usually C-B-E, so check that too. |
| D4, D5 | 2 | **1N4007** (flyback) | **Micro Robotics** | [1N4007-10](https://www.robotics.org.za/1N4007-10) | 10 / R15 | In stock / In stock | [1N4148](https://www.robotics.org.za/1N4148) would also work (72mA coil) |
| D6, D7 | 2 | **Red LED 3mm** (relay-on indicator) | **Micro Robotics** | [LED-03-RED](https://www.robotics.org.za/LED-03-RED) | 25 / R10 | In stock / **No stock** | Order from Centurion, or use [LED-RED-5MM](https://www.robotics.org.za/LED-RED-5MM) (in stock at both). The footprint suits 3mm; a 5mm LED fits with its body raised. |
| F1 | 1 | PTC resettable fuse 0.5A hold / 1A trip, 24V, **1206 SMD** | **Micro Robotics** | [PTC05A24V](https://www.robotics.org.za/PTC05A24V) | 10 / R10 | In stock / In stock | |
| D1, D3 | 2 | **1N5822** Schottky, 3A 40V, DO-201AD | **Micro Robotics** | [1N5822-TH](https://www.robotics.org.za/1N5822-TH) | 10 / R16 | In stock / In stock | Replaces 1N5819 (not carried). Larger body and 1.3mm leads. |
| D2 | 1 | **P6KE18A** TVS, unidirectional, 15.3V standoff | **Communica** | [P6KE 18A](https://www.communica.co.za/products/p6ke-18a) | 1 / R4.50 | Available | Micro Robotics only has the P6KE50A (wrong voltage). Optional part: the board works without it. **Don't** use the bidirectional "CA" versions or anything under 15V standoff. |
| C1 | 1 | Electrolytic **100µF** radial | **On hand** | [CAP-100UF-25V](https://www.robotics.org.za/CAP-100UF-25V) | 10 / R8 | In stock / In stock | From the [CAPKIT](https://www.robotics.org.za/CAPKIT) (100µF **35V**, 6 × 7mm). |
| C2, C4, C7, C8 | 4 | Ceramic **100nF**, radial 5.08mm | **On hand** | [100NF-P508](https://www.robotics.org.za/100NF-P508) | 25 / R6 | In stock / In stock | From the CAPKIT (100nF 50V, 5.08mm pitch). The kit has 5 and 4 are needed. |
| C3 | 1 | Electrolytic **10µF** radial | **On hand** | [CAP-10UF-35V](https://www.robotics.org.za/CAP-10UF-35V) | 10 / R10 | In stock / In stock | From the CAPKIT (10µF **50V** electrolytic, 4 × 7mm). |
| C5, C6 | 2 | **Ceramic 10µF 25V X5R, 1206 SMD** (CEXT, sees 5V). **The CAPKIT's 10µF electrolytic is not suitable here.** | **Micro Robotics** | [CL31A106KAHNNNE](https://www.robotics.org.za/CL31A106KAHNNNE) | 100 / R18 | In stock / In stock | Samsung CL31A = X5R. Low leakage, so it's suitable for the timer. |
| R1, R2 | 2 | Resistor 100k ¼W | **Micro Robotics** | [RES-100K-50](https://www.robotics.org.za/RES-100K-50) | 50 / R16 | In stock / In stock | 5% carbon film |
| R3, R4 | 2 | Resistor **1M** ¼W (REXT) | **Micro Robotics** | [RES-1M-50](https://www.robotics.org.za/RES-1M-50) | 50 / R16 | In stock / **No stock** | Order from Centurion. 5% carbon film is fine; the timeout only needs to stay roughly between 4 and 30 s. |
| R5, R6, R13, R14 | 4 | Resistor 10k ¼W (trigger delay; base pull-downs) | **Micro Robotics** | [RES-10K-025](https://www.robotics.org.za/RES-10K-025) | 50 / R16 | In stock / In stock | |
| R7–R10, R15, R16 | 6 | Resistor **1k**, **1206 SMD** (base resistors, GPIO series, LED resistors) | **Micro Robotics** | [RES-1K-1206](https://www.robotics.org.za/RES-1K-1206) | 100 | In stock / In stock | The through-hole 1k ([RES-1K-025W](https://www.robotics.org.za/RES-1K-025W)) is out of stock. |
| R11, R12 | 2 | Resistor **100Ω**, **1206 SMD** (in series with CEXT, power-down protection) | **Micro Robotics** | [RES-100-1206](https://www.robotics.org.za/RES-100-1206) | 50 | In stock / In stock | The through-hole 100Ω ([RES-100E-025W](https://www.robotics.org.za/RES-100E-025W)) is out of stock |
| (crossings) | a few | **0Ω link** ¼W, only if the PCB layout needs jumper crossings | **Micro Robotics** | [RES-0E-50](https://www.robotics.org.za/RES-0E-50) | 50 / R16 | In stock / In stock | Optional; decided during layout |
| PCB | 1 | Double-sided copper-clad board, **CNC-milled** by the user (isolation routing) | **On hand** | n/a | n/a | n/a | No plating, solder mask or silkscreen. See the README section on CNC-milling rules. |

## Wiring and mounting

| Item | Qty | Source | Code | Pack / price | Stock (C / S) | Notes |
|---|-----|---|---|---|---|---|
| Hook-up wire 18 AWG, red and black | 1 | **Micro Robotics** | [AWG18-UL1007-RB-5M](https://www.robotics.org.za/AWG18-UL1007-RB-5M) | 5m each / R36 | In stock / In stock | Battery and AC runs |
| Bootlace ferrules | 1 kit | **On hand** | [CRIMP-400](https://www.robotics.org.za/CRIMP-400) | 400 / R118 | In stock / In stock | Ferrules need to suit 18 AWG (0.75–1.0mm²) wire, and a ferrule crimper is needed. |
| Heat shrink | 1 | **On hand** | [HEAT-3MM-BLK](https://www.robotics.org.za/HEAT-3MM-BLK) | 10 × 200mm / R8 | In stock / In stock | General use (fuse holder joints) |
| In-line blade fuse holder | 1 | **Micro Robotics** | [FUSE-INLINE-40A](https://www.robotics.org.za/FUSE-INLINE-40A) | 1 / R28 | In stock / In stock | **Recommended**, on battery + near the battery |
| Blade fuse 3A | 1 | **Micro Robotics** | [BLADE-3A](https://www.robotics.org.za/BLADE-3A) | 10 / R15 | In stock / In stock | |
| M3 nylon spacers, 15mm, with screws and nuts | 2–4 sets | **Micro Robotics** | [SPACE-M3-L15-KIT](https://www.robotics.org.za/SPACE-M3-L15-KIT) | 20 / R22 | In stock / In stock | The 10mm kit ([SPACE-M3-L10-KIT](https://www.robotics.org.za/SPACE-M3-L10-KIT)) is out of stock |
| **External WiFi antenna** 2.4GHz, flexible PCB 38 × 10mm, U.FL/IPEX on a ~100mm lead (**optional**) | 1 | **Micro Robotics** | [BAT-P60-WIFI-2](https://www.robotics.org.za/BAT-P60-WIFI-2) | 1 / R18 | In stock / In stock | For the SuperMini V2's IPEX socket, if WiFi is weak inside the panel housing (the module's antenna end points into the board). 3dBi omni, 2.4–5.9GHz; stick it to the inside of the housing, away from metal where possible. To use it, move the V2's small antenna-select link from the ceramic antenna to the IPEX socket. **Alternative:** Communica [BDD ENCL WIFI ANTENNA 2,4GHZ 4DB](https://www.communica.co.za/products/bdd-encl-wifi-antenna-2-4ghz-4db) (R25, 4dBi, IPEX on lead; check the plug is IPEX-1/U.FL, the listing says "IPEX13"). |

## No longer needed (on-board relay redesign)

| Item | Status |
|---|---|
| REL-2CHAN-335V relay module | **On hand, now a spare** (useful for bench tests) |
| J5, J6 (relay COM/NC terminals), J7 JST-XH + JST-XH-4P-300 kit | Removed: no board-to-board wiring |
| DPSHELL-5P, DuPont terminals (DUP-PIN-FEM-100 / DUP-4P-254-L200) | Removed: no control lead |
| JP1–JP4 Q/Q̅ links, R7/R8 220Ω (RES-220-1206) | Removed: we set the trigger polarity ourselves. R7/R8 are now 1k base resistors. |

## Order summary

**Micro Robotics:** 5713, SRD-05VDC-SL-C (4-pack), 2N2222A-TO-92, 1N4007-10,
LED-03-RED (Centurion) or LED-RED-5MM, IC-SOC-16P, PTC05A24V, 1N5822-TH,
CL31A106KAHNNNE, RES-100K-50, RES-1M-50 (Centurion), RES-10K-025, RES-1K-1206,
RES-100-1206, RES-0E-50 (optional), AWG18-UL1007-RB-5M, FUSE-INLINE-40A,
BLADE-3A, SPACE-M3-L15-KIT, BAT-P60-WIFI-2 (optional antenna).

**Communica:** 74HCT4538E (×1, or ×2 as a spare), P6KE 18A (×1).

**PCB:** milled in-house from on-hand copper-clad board.

## Design changes made to fit available stock

| Was | Now | Why it's fine |
|-----|-----|---|
| 1N5819 (D1, D3) | 1N5822 | Same job, higher current rating. Only the footprint changes (DO-201AD). |
| C1 47µF 25V | 100µF | More bulk capacitance damps spikes better. The inrush at hook-up is limited by F1 and D1. |
| C2 1µF | 100nF | C1 already provides bulk capacitance. 100nF handles high-frequency decoupling. |
| C7, C8 1nF (10µs trigger delay) | 100nF (1ms delay) | The delay only needs to be longer than the reset release. 1ms of relay delay doesn't matter, and the Schmitt input handles the slow edge. |
| CEXT 10µF radial X7R | 10µF 1206 X5R (Samsung) | No through-hole 10µF ceramic available. 1206 is hand-solderable. |
| 74HC4538 at 3.3V | **74HCT4538E at 5V** (Communica) | TTL inputs accept the ESP's 3.3V, and it drives the transistor bases with a full 5V. |
| BAT85 DEXT diodes | 100Ω in series with CEXT (R11, R12) | TI's recommended power-down protection. It adds no leakage across the 1M timing resistor. |
| n/a | 1k series resistors R9, R10 | Protect the ESP if it drives a GPIO high while the 5V rail is off (USB-only power) |
| P6KE18A (Micro Robotics) | P6KE 18A (Communica) | Micro Robotics doesn't carry it. It's optional anyway. |
| Relay module + wiring | On-board SRD-05VDC-SL-C + 2N2222A drivers | Fewer terminals in the panel power paths, no inter-board wiring. See the README decisions log. |

## Micro Robotics alternatives considered and rejected

| Part | Why not |
|---|---|
| [555-DIP](https://www.robotics.org.za/555-DIP) instead of the 74HCT4538 | Would need 2 × 555 plus an edge-detect transistor stage per channel. A bipolar NE555 also draws about 3–6mA each, which would roughly double the idle current. |
| [T10UF-35V](https://www.robotics.org.za/T10UF-35V) tantalum for CEXT | 3.5µA max leakage, comparable to the timing current. Use the Samsung ceramic instead. |
| [P6KE50A](https://www.robotics.org.za/P6KE50A) TVS | The listing is contradictory (titled "5V", part number means 50V). Either value is wrong for a 12V battery. |
| [MF-NSMF050-2](https://www.robotics.org.za/MF-NSMF050-2) PTC | Rated 13.2V, below the 13.8V battery float voltage. |
| [WDS250-500](https://www.robotics.org.za/WDS250-500) PTC | Through-hole, but only 0.25A hold. Kept as a fallback for F1. |

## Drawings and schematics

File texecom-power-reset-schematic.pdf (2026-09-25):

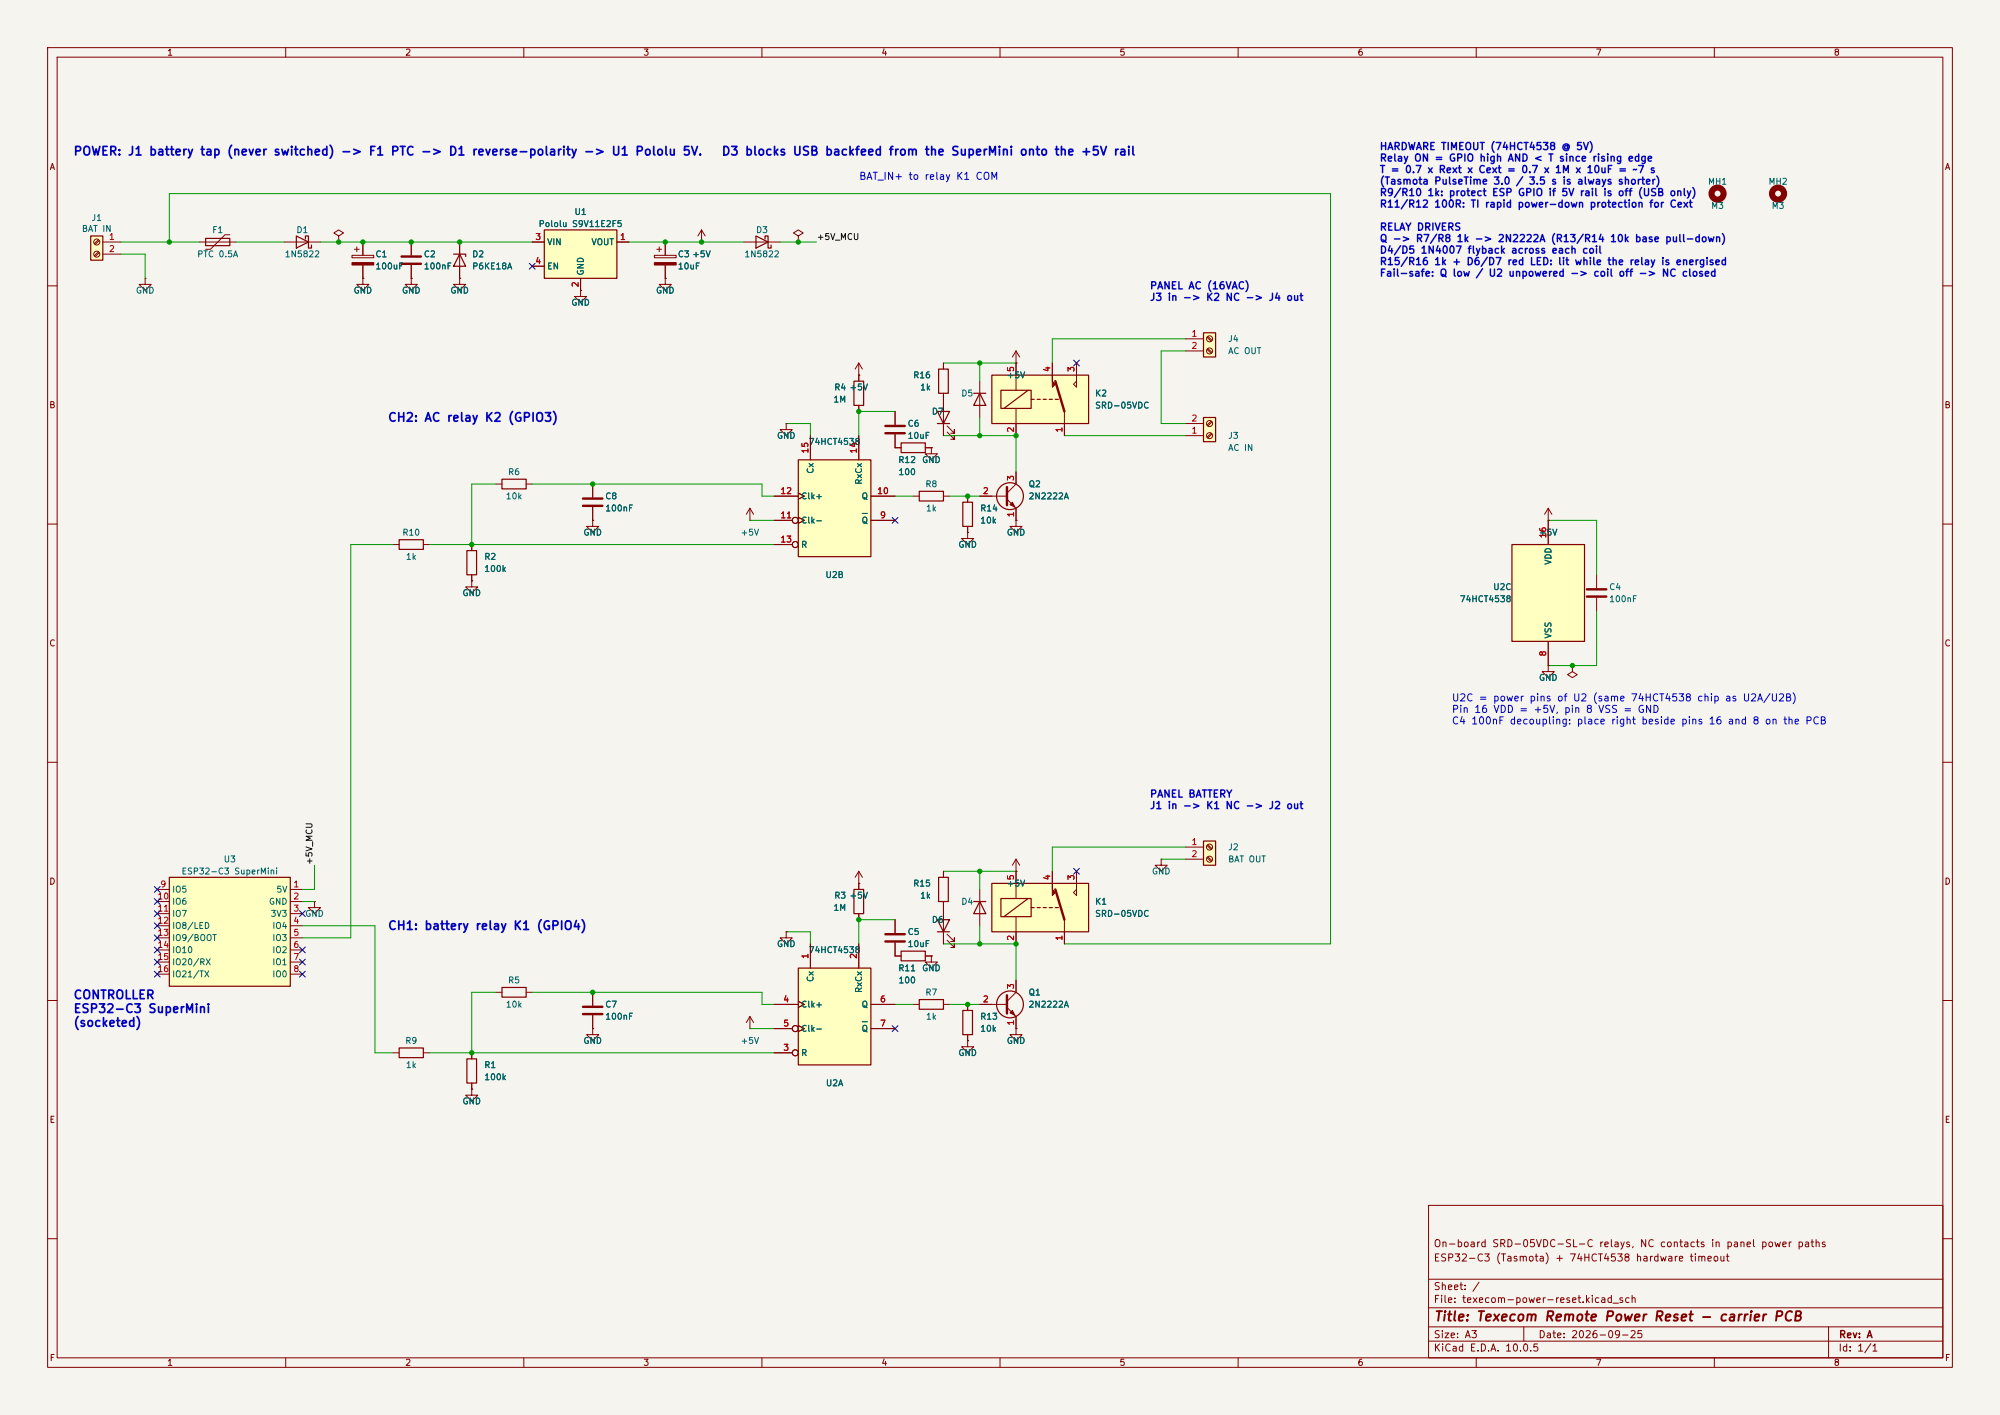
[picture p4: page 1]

HARDWARE TIMEOUT (74HCT4538 @ 5V)
Relay ON = GPIO high AND < T since rising edge
T = 0.7 x Rext x Cext = 0.7 x 1M x 10uF = ~7 s
(Tasmota PulseTime 3.0 / 3.5 s is always shorter) R9/R10 1k: protect ESP GPIO if 5V rail is off (USB only) R11/R12 100R: TI rapid power-down protection for Cext

RELAY DRIVERS
Q -> R7/R8 1k -> 2N2222A (R13/R14 10k base pull-down) D4/D5 1N4007 flyback across each coil

R15/R16 1k + D6/D7 red LED: lit while the relay is energised
Fail-safe: Q low / U2 unpowered -> coil off -> NC closed

U2C = power pins of U2 (same 74HCT4538 chip as U2A/U2B)
Pin 16 VDD = +5V, pin 8 VSS = GND
C4 100nF decoupling: place right beside pins 16 and 8 on the PCB

On-board SRD-05VDC-SL-C relays, NC contacts in panel power paths R1

Sheet: /
File: texecom-power-reset.kicad_sch
Title: Texecom Remote Power Reset - carrier PCB

Size: A3 | Rev: A | F Date: 2026-09-25
KiCad E.D.A. 10.0.5 | Id: 1/1

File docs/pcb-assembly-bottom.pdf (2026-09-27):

# Texecom power reset · rev A · bottom side (solder side)

## Bottom-side SMD parts (1206)

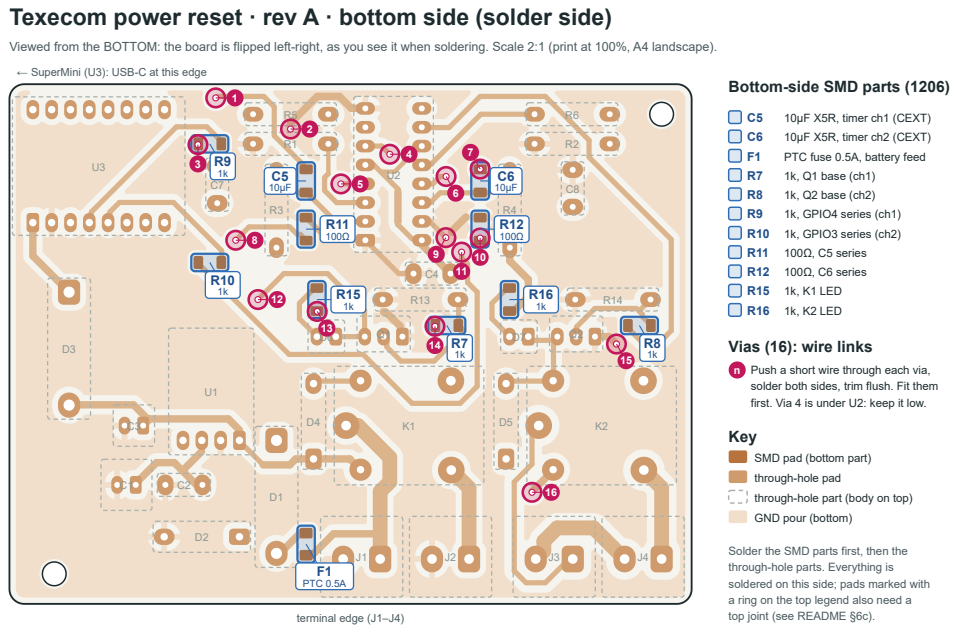
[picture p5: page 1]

Viewed from the BOTTOM: the board is flipped left-right, as you see it when soldering. Scale 2:1 (print at 100%, A4 landscape).

← SuperMini (U3): USB-C at this edge

n Push a short wire through each via,
solder both sides, trim flush. Fit them
first. Via 4 is under U2: keep it low.
Key
SMD pad (bottom part)
through-hole pad
through-hole part (body on top)
GND pour (bottom)

Solder the SMD parts first, then the
through-hole parts. Everything is
soldered on this side; pads marked with
a ring on the top legend also need a
top joint (see README §6c).

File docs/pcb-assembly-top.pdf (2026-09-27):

# Texecom power reset · rev A · top side (component side)

## Top-side parts

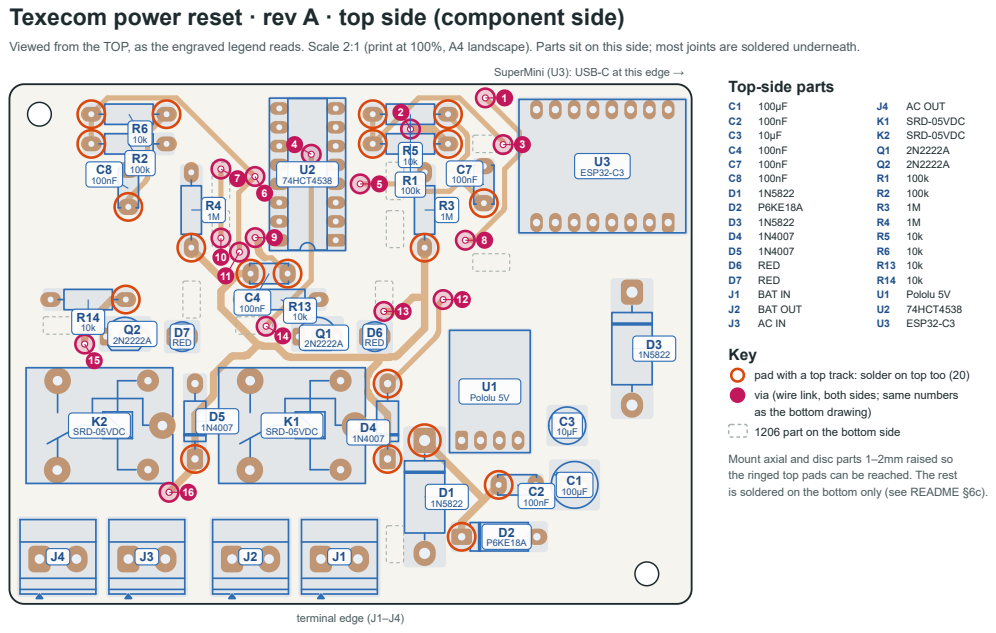
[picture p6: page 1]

Viewed from the TOP, as the engraved legend reads. Scale 2:1 (print at 100%, A4 landscape). Parts sit on this side; most joints are soldered underneath.

SuperMini (U3): USB-C at this edge →

Key
pad with a top track: solder on top too (20)
via (wire link, both sides; same numbers
as the bottom drawing)
1206 part on the bottom side

Mount axial and disc parts 1–2mm raised so
the ringed top pads can be reached. The rest
is soldered on the bottom only (see README §6c).

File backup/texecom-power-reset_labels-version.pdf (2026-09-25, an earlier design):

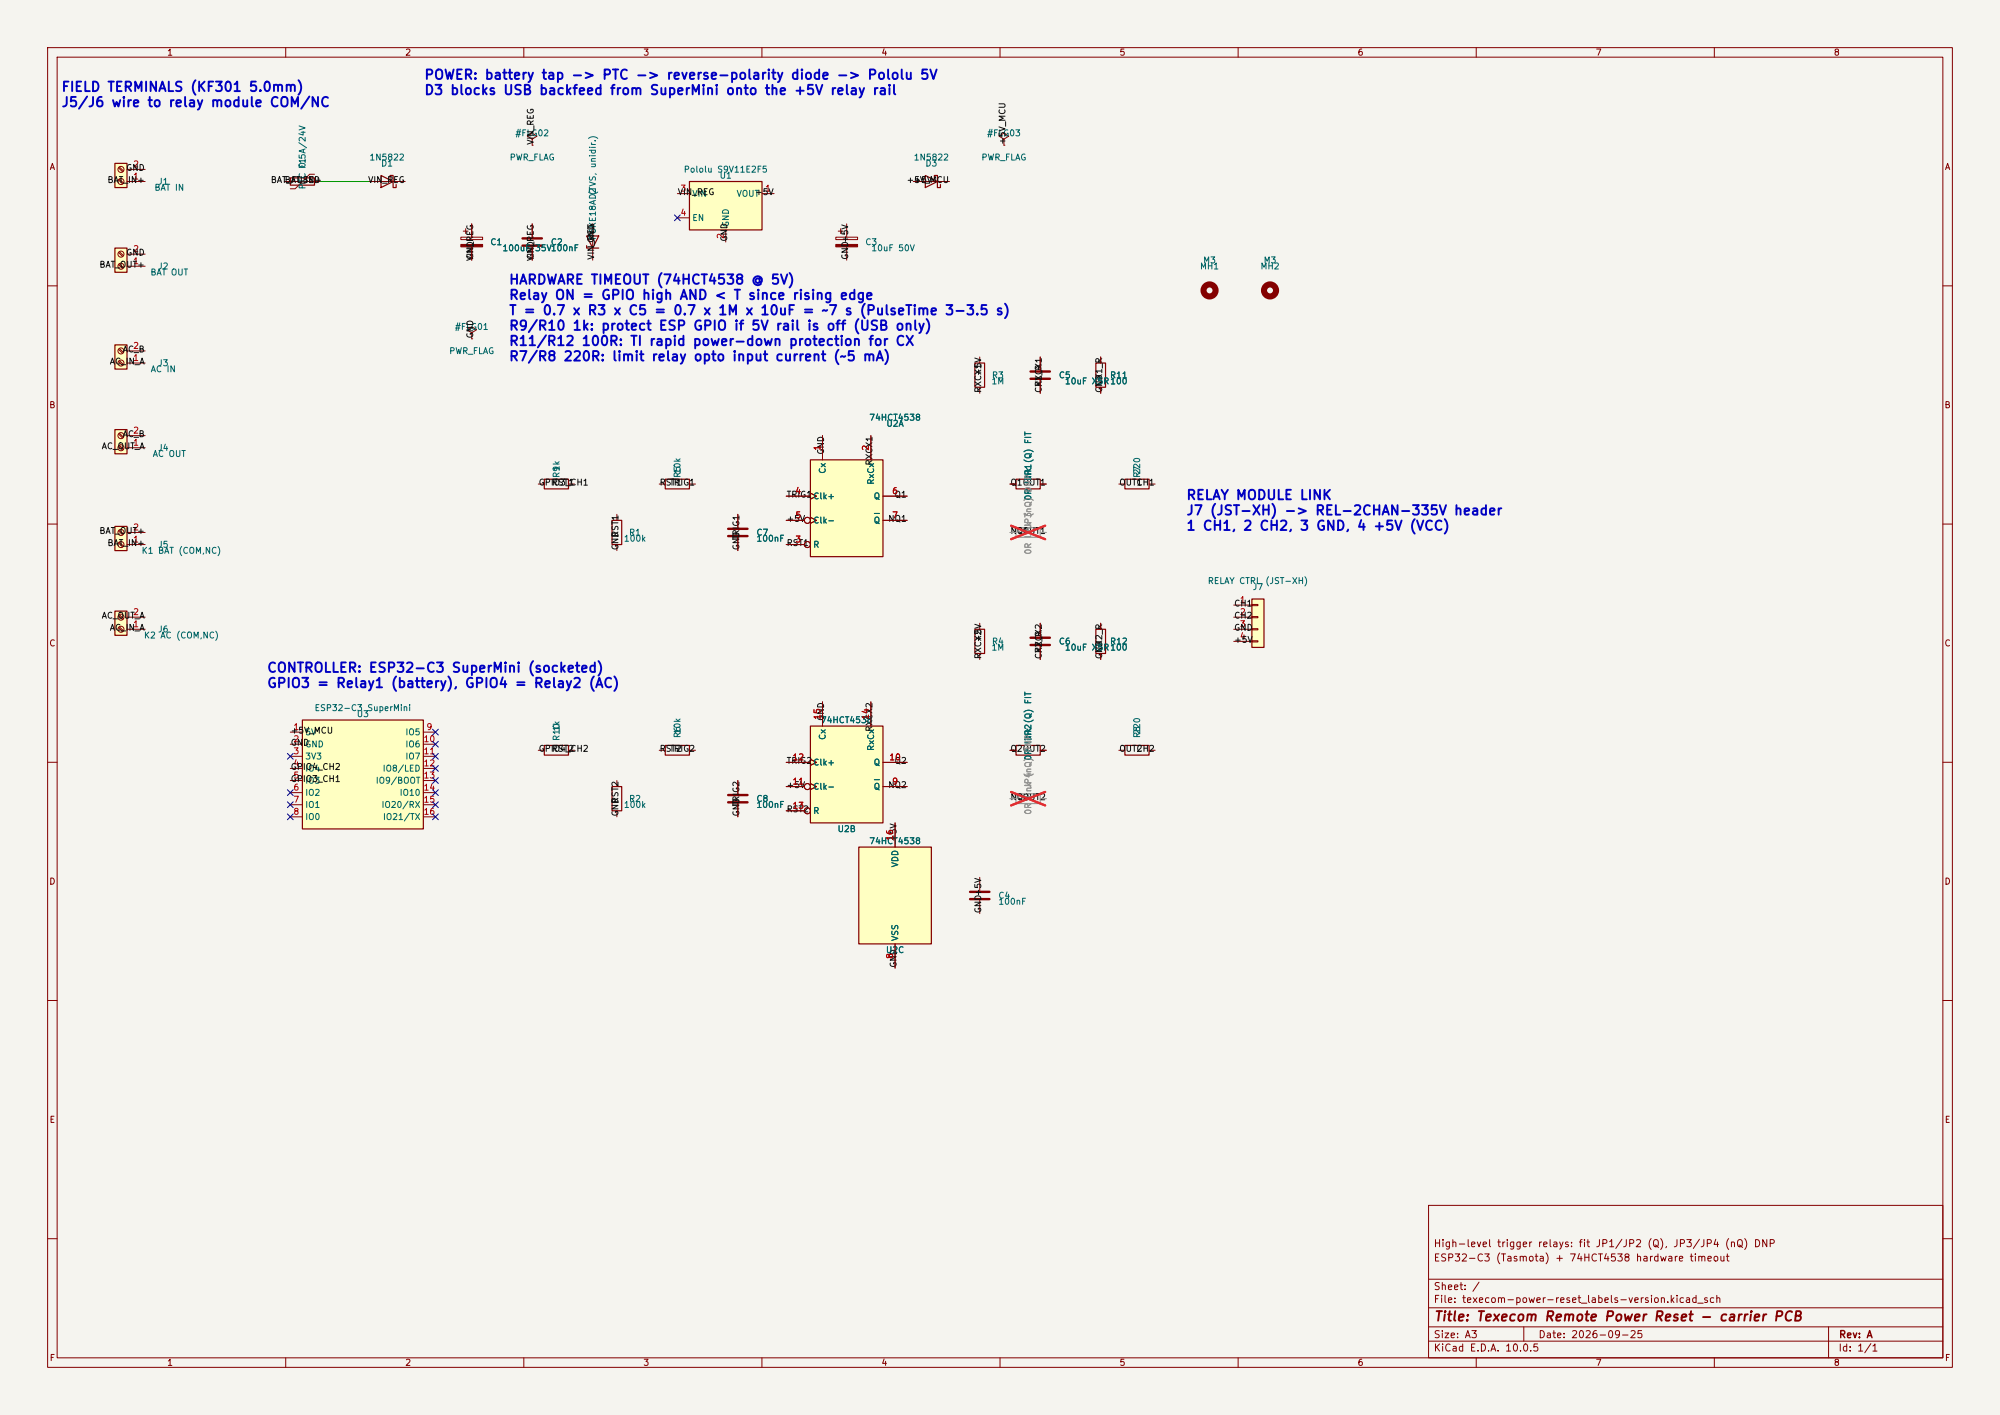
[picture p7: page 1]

POWER: battery tap -> PTC -> reverse-polarity diode -> Pololu 5V
D3 blocks USB backfeed from SuperMini onto the +5V relay rail
#FLG02 PWR_FLAG R91k

FIELD TERMINALS (KF301 5.0mm) J5/J6 wire to relay module COM/NC

J7 RELAY CTRL (JST-XH) C310uF 50V

HARDWARE TIMEOUT (74HCT4538 @ 5V)
Relay ON = GPIO high AND < T since rising edge
T = 0.7 x R3 x C5 = 0.7 x 1M x 10uF = ~7 s (PulseTime 3-3.5 s) R9/R10 1k: protect ESP GPIO if 5V rail is off (USB only) R11/R12 100R: TI rapid power-down protection for CX

R7/R8 220R: limit relay opto input current (~5 mA)

RELAY MODULE LINK
J7 (JST-XH) -> REL-2CHAN-335V header
1 CH1, 2 CH2, 3 GND, 4 +5V (VCC)

Sheet: /
File: texecom-power-reset_labels-version.kicad_sch
Title: Texecom Remote Power Reset - carrier PCB

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

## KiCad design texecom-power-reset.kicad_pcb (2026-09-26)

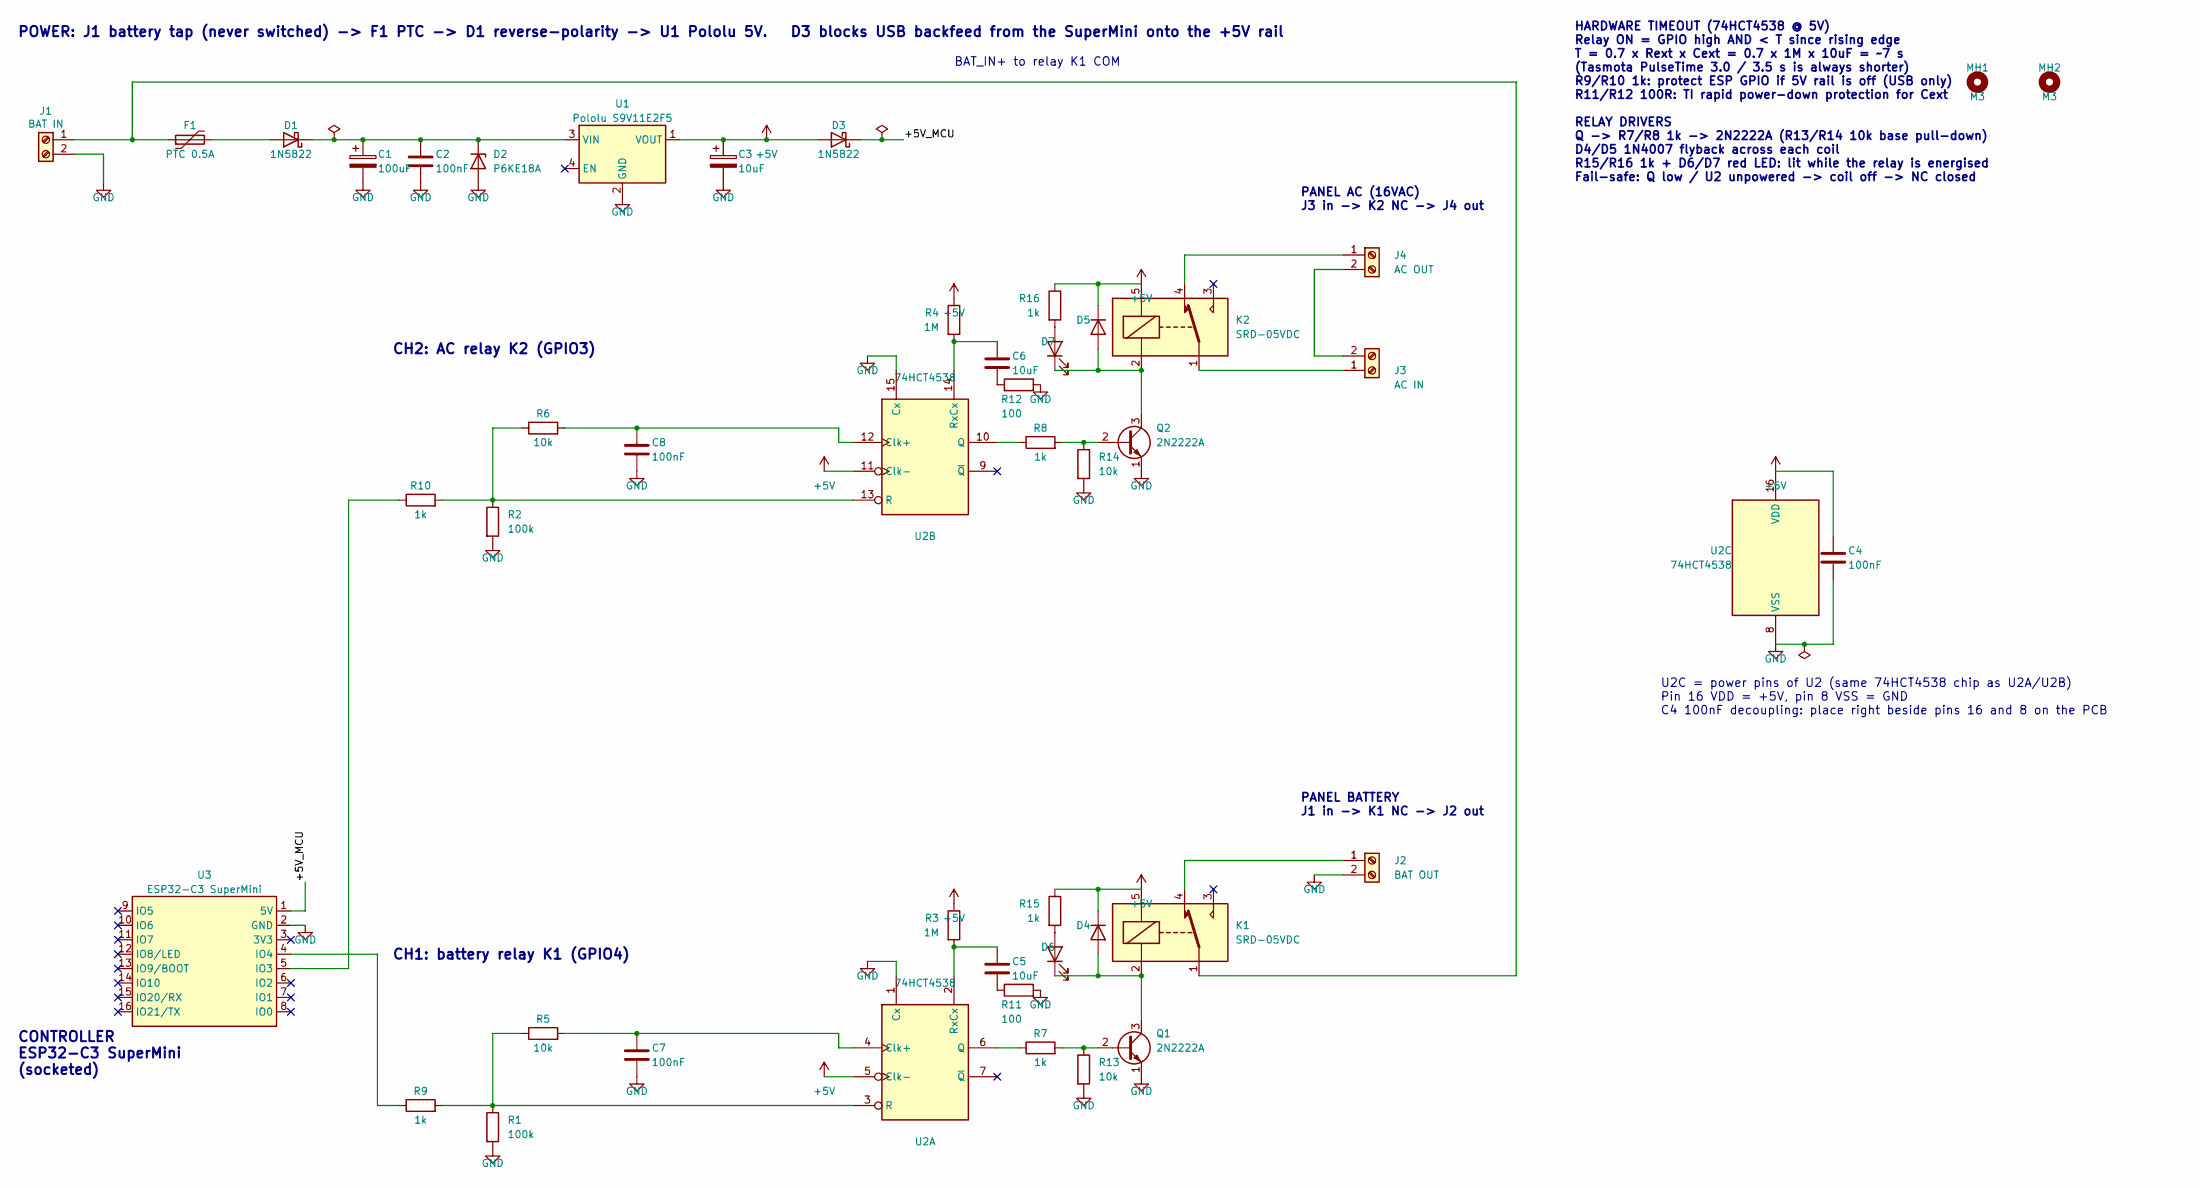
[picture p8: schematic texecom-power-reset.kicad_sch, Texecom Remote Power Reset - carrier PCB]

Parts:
C1: 100uF; CP_Radial_D6.3mm_P2.50mm_Mill
C2, C4, C7, C8: 100nF; C_Disc_D5.0mm_W2.5mm_P5.00mm_Mill
C3: 10uF; CP_Radial_D5.0mm_P2.50mm_Mill
C5, C6: 10uF; C_1206_3216Metric_Pad1.33x1.80mm_HandSolder
D1, D3: 1N5822; D_DO-201AD_P15.24mm_Mill
D2: P6KE18A; D_DO-15_P10.16mm_Mill
D4, D5: 1N4007; D_DO-41_P10.16mm_Mill
D6, D7: RED; LED_D3.0mm_Mill
F1: PTC 0.5A; Fuse_1206_3216Metric_Pad1.42x1.75mm_HandSolder
J1: BAT IN; KF301-2P_P5.00mm_Mill
J2: BAT OUT; KF301-2P_P5.00mm_Mill
J3: AC IN; KF301-2P_P5.00mm_Mill
J4: AC OUT; KF301-2P_P5.00mm_Mill
K1, K2: SRD-05VDC; Relay_SRD_Form_C_Mill
MH1, MH2: M3; MountingHole_3.2mm_M3
Q1, Q2: 2N2222A; TO-92_Inline_Wide_Mill
R1, R2: 100k; R_Axial_DIN0207_P10.16mm_Mill
R3, R4: 1M; R_Axial_DIN0207_P10.16mm_Mill
R5, R6, R13, R14: 10k; R_Axial_DIN0207_P10.16mm_Mill
R7, R8, R9, R10, R15, R16: 1k; R_1206_3216Metric_Pad1.30x1.75mm_HandSolder
R11, R12: 100; R_1206_3216Metric_Pad1.30x1.75mm_HandSolder
U1: Pololu S9V11E2F5; Pololu_S9V11E2x_Mill
U2: 74HCT4538; DIP-16_W7.62mm_Socket_Mill
U3: ESP32-C3 SuperMini; ESP32-C3-SuperMini_Mill

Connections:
+5V: C3.1, C4.1, D3.2 (A), D4.1 (K), D5.1 (K), K1.5, K2.5, R3.1, R4.1, R15.1, R16.1, U1.1 (VOUT), U2.5 (Clk-), U2.11 (Clk-), U2.16 (VDD)
+5V_MCU: D3.1 (K), U3.1 (5V)
GND: C1.2, C2.2, C3.2, C4.2, C7.2, C8.2, D2.2 (A), J1.2, J2.2, Q1.1 (E), Q2.1 (E), R1.2, R2.2, R11.2, R12.2, R13.2, R14.2, U1.2 (GND), U2.1 (Cx), U2.8 (VSS), U2.15 (Cx), U3.2 (GND)
unnamed: C5.2, R11.1
unnamed: C6.2, R12.1
unnamed: D1.2 (A), F1.2
unnamed: C1.1, C2.1, D1.1 (K), D2.1 (K), U1.3 (VIN)
unnamed: D4.2 (A), D6.1 (K), K1.2, Q1.3 (C)
unnamed: D5.2 (A), D7.1 (K), K2.2, Q2.3 (C)
unnamed: D6.2 (A), R15.2
unnamed: D7.2 (A), R16.2
unnamed: F1.1, J1.1, K1.1
unnamed: J2.1, K1.4
unnamed: J3.1, K2.1
unnamed: J3.2, J4.2
unnamed: J4.1, K2.4
unnamed: Q1.2 (B), R7.2, R13.1
unnamed: Q2.2 (B), R8.2, R14.1
unnamed: C7.1, R5.2, U2.4 (Clk+)
unnamed: R7.1, U2.6 (Q)
unnamed: R1.1, R5.1, R9.2, U2.3 (R)
unnamed: C5.1, R3.2, U2.2 (RxCx)
unnamed: C8.1, R6.2, U2.12 (Clk+)
unnamed: R8.1, U2.10 (Q)
unnamed: R2.1, R6.1, R10.2, U2.13 (R)
unnamed: C6.1, R4.2, U2.14 (RxCx)
unnamed: R10.1, U3.5 (IO3)
unnamed: R9.1, U3.4 (IO4)

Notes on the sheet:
CH1: battery relay K1 (GPIO4)
POWER: J1 battery tap (never switched) -> F1 PTC -> D1 reverse-polarity -> U1 Pololu 5V. D3 blocks USB backfeed from the SuperMini onto the +5V rail
BAT_IN+ to relay K1 COM
PANEL AC (16VAC) J3 in -> K2 NC -> J4 out
PANEL BATTERY J1 in -> K1 NC -> J2 out
CONTROLLER ESP32-C3 SuperMini (socketed)
CH2: AC relay K2 (GPIO3)
HARDWARE TIMEOUT (74HCT4538 @ 5V) Relay ON = GPIO high AND < T since rising edge T = 0.7 x Rext x Cext = 0.7 x 1M x 10uF = ~7 s (Tasmota PulseTime 3.0 / 3.5 s is always shorter) R9/R10 1k: protect ESP GPIO if 5V rail is off (USB only) R11/R12 100R: TI rapid power-down protection for Cext RELAY DRIV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
U2C = power pins of U2 (same 74HCT4538 chip as U2A/U2B) Pin 16 VDD = +5V, pin 8 VSS = GND C4 100nF decoupling: place right beside pins 16 and 8 on the PCB

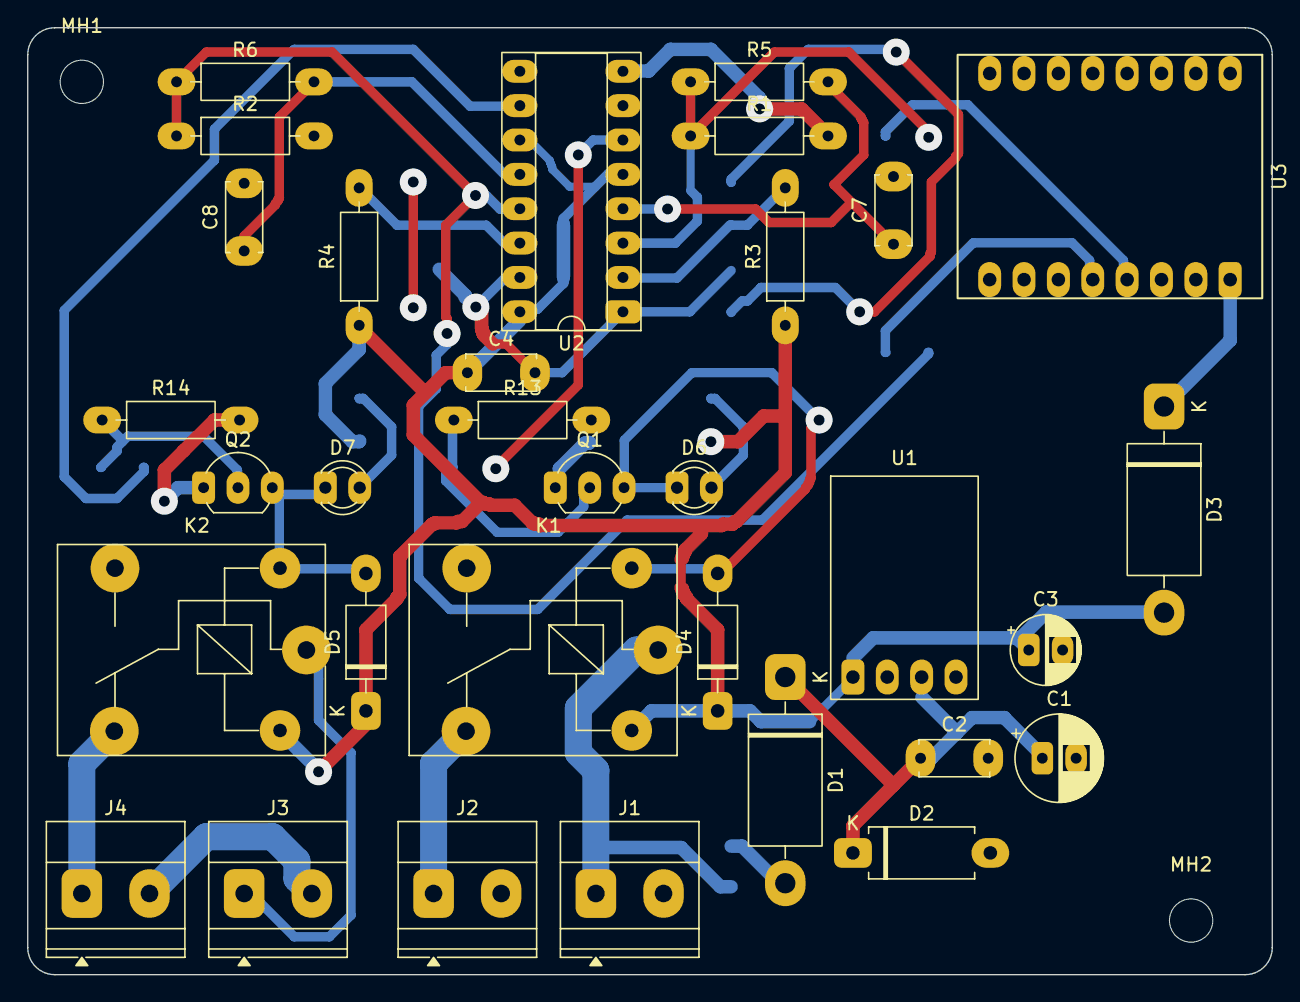
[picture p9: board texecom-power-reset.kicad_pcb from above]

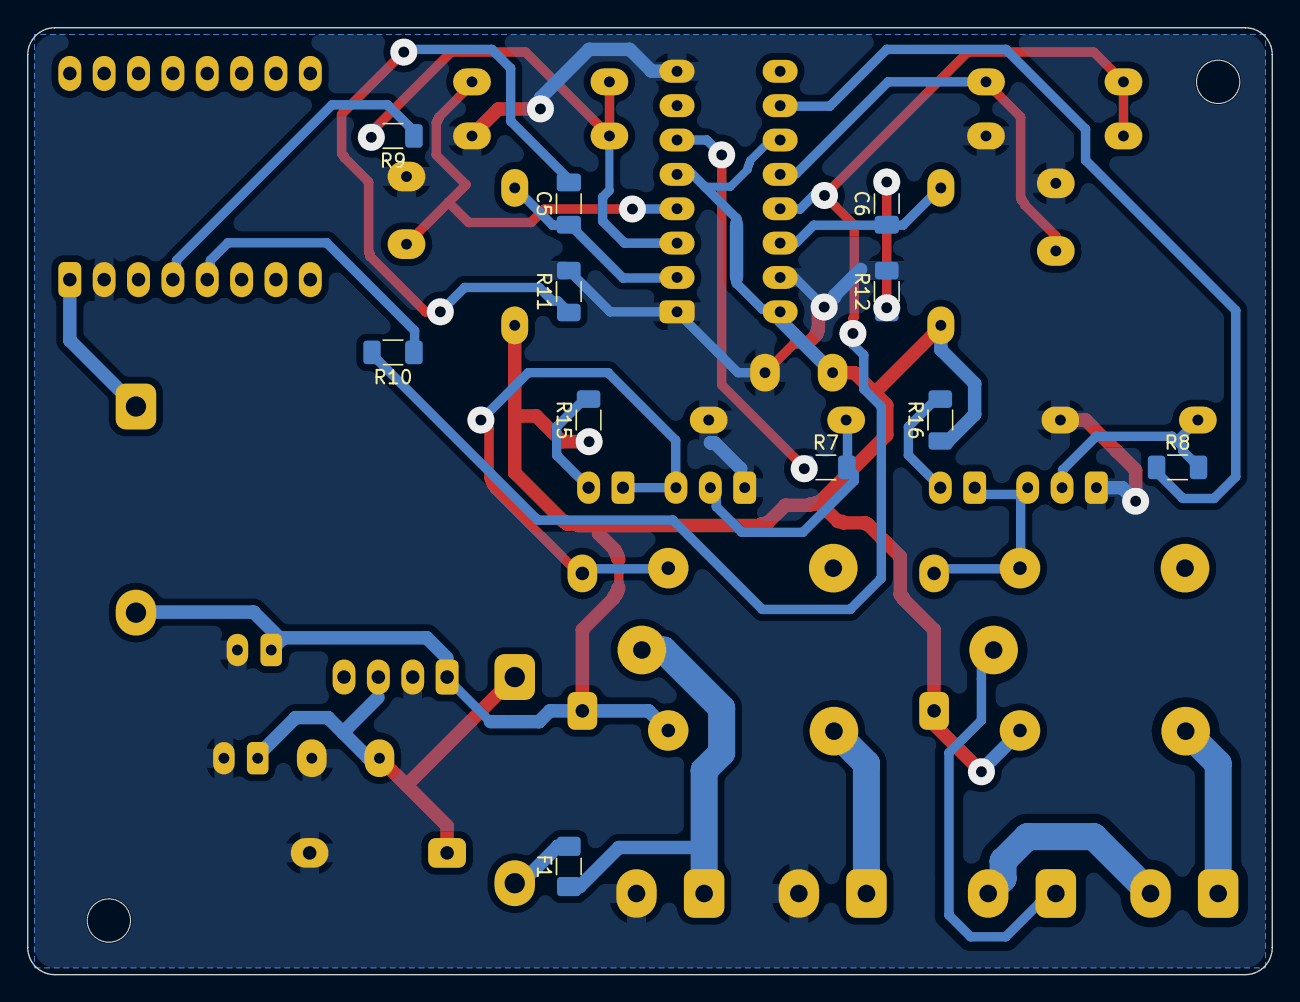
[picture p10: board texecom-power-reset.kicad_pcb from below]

Board: 2 copper layers, 92.0 x 70.0 mm, 45 parts (11 on the bottom side), 28 nets.

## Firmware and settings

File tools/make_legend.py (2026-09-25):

"""Build the Mill_Legend layer (User.1): component outlines, polarity marks, references and terminal labels,
kept clear of all top copper so a shallow V-bit engrave never cuts a track or pad.

Usage (KiCad's own Python, which has pcbnew; shapely comes from KiCad's 3rd-party site-packages):
    "C:/Program Files/KiCad/10.0/bin/python.exe" tools/make_legend.py texecom-power-reset.kicad_pcb

Close the board in KiCad first. The script renames User.1 to Mill_Legend, deletes whatever is on it and
rebuilds the legend, so rerun it after any layout change. Outlines are clipped wherever they come near top copper;
texts are placed whole at the first clear candidate spot (PREFERRED lists hand-picked spots for crowded areas).
Then export the layer:  kicad-cli pcb export gerbers --layers User.1 ...
"""
import math
import sys
sys.path.append('C:/Users/Johan/Documents/KiCad/10.0/3rdparty/Python311/site-packages')
import pcbnew
from shapely.geometry import LineString, Point, Polygon, box
from shapely.ops import unary_union

PCB = sys.argv[1]
S = 1e6
LAYER = pcbnew.User_1
LINE_W = 0.15          # engraved line width (V-bit at shallow depth)
MARGIN = 0.35          # clearance from any top copper / hole to the engrave centreline edge
EDGE_INSET = 1.0       # keep legend this far inside the board edge
MIN_PIECE = 0.8        # drop clipped fragments shorter than this
TXT_H = 1.2            # reference text height
LBL_H = 1.5            # terminal label height
TXT_T = 0.15
DOT_R = 0.5            # radius of the "solder on top too" ring beside a pad

# hand-picked first-choice spots for crowded areas (x, y, angle); tried before the automatic search
PREFERRED = {  # (x, y, angle, text height)
    'C4': [(135.0, 125.5, 0, 1.0), (135.0, 125.3, 0, 1.0), (135.0, 125.7, 0, 1.0), (135.0, 125.5, 0, 0.9)],
    'R13': [(135.0, 129.0, 0, 1.0), (135.0, 129.0, 0, 0.9)],
}
TERMINAL_LABELS = {'J1': 'BAT IN', 'J2': 'BAT OUT', 'J3': 'AC IN', 'J4': 'AC OUT'}
PIN_MARKS = {('J1', '1'): '+', ('J1', '2'): '-', ('J2', '1'): '+', ('J2', '2'): '-'}

b = pcbnew.LoadBoard(PCB)
b.SetLayerName(LAYER, 'Mill_Legend')
ls = b.GetEnabledLayers()
ls.AddLayer(LAYER)
b.SetEnabledLayers(ls)

# remove previous legend
for d in [d for d in b.GetDrawings() if d.GetLayer() == LAYER]:
    b.Delete(d)


def xy(v):
    return (v.x / S, v.y / S)


def sps_polys(sps):
    out = []
    for i in range(sps.OutlineCount()):
        o = sps.Outline(i)
        outer = [xy(o.CPoint(k)) for k in range(o.PointCount())]
        holes = []
        for j in range(sps.HoleCount(i)):
            h = sps.Hole(i, j)
            holes.append([xy(h.CPoint(k)) for k in range(h.PointCount())])
        if len(outer) >= 3:
            out.append(Polygon(outer, holes).buffer(0))
    return out


# ---- obstacles: everything on the top copper plus every hole ----
obst = []
for p in b.GetPads():
    if p.IsOnLayer(pcbnew.F_Cu):
        sps = pcbnew.SHAPE_POLY_SET()
        p.TransformShapeToPolygon(sps, pcbnew.F_Cu, 0, 5000, pcbnew.ERROR_OUTSIDE)
        obst += sps_polys(sps)
    if p.GetDrillSize().x > 0:
        obst.append(Point(xy(p.GetPosition())).buffer(max(p.GetDrillSize().x, p.GetDrillSize().y) / 2 / S))
for t in b.GetTracks():
    if t.Type() == pcbnew.PCB_VIA_T:
        obst.append(Point(xy(t.GetPosition())).buffer(t.GetWidth(pcbnew.F_Cu) / 2 / S))
    elif t.GetLayer() == pcbnew.F_Cu:
        obst.append(LineString([xy(t.GetStart()), xy(t.GetEnd())]).buffer(t.GetWidth() / 2 / S))
for z in b.Zones():
    if not z.GetIsRuleArea() and z.IsOnLayer(pcbnew.F_Cu):
        obst += sps_polys(z.GetFilledPolysList(pcbnew.F_Cu))
blocked = unary_union(obst).buffer(MARGIN + LINE_W / 2)

bb = b.GetBoardEdgesBoundingBox()
inside = box(bb.GetX() / S + EDGE_INSET, bb.GetY() / S + EDGE_INSET,
             bb.GetRight() / S - EDGE_INSET, bb.GetBottom() / S - EDGE_INSET)
allowed = inside.difference(blocked)


# ---- outlines ----
def arc_pts(c, r, a0, a1, n=None):
    n = n or max(8, int(abs(a1 - a0) * r / 0.3))
    return [(c[0] + r * math.cos(a0 + (a1 - a0) * i / n), c[1] + r * math.sin(a0 + (a1 - a0) * i / n)) for i in range(n + 1)]


def shape_lines(g):
    st = g.GetShape()
    if st == pcbnew.SHAPE_T_SEGMENT:
        return [[xy(g.GetStart()), xy(g.GetEnd())]]
    if st == pcbnew.SHAPE_T_RECTANGLE:
        c = [xy(v) for v in g.GetRectCorners()]
        return [c + [c[0]]]
    if st == pcbnew.SHAPE_T_CIRCLE:
        c = xy(g.GetCenter())
        return [arc_pts(c, g.GetRadius() / S, 0, 2 * math.pi, 64)]
    if st == pcbnew.SHAPE_T_ARC:
        c = xy(g.GetCenter())
        s, e = xy(g.GetStart()), xy(g.GetEnd())
        r = math.hypot(s[0] - c[0], s[1] - c[1])
        a0 = math.atan2(s[1] - c[1], s[0] - c[0])
        a1 = math.atan2(e[1] - c[1], e[0] - c[0])
        m = xy(g.GetArcMid())
        am = math.atan2(m[1] - c[1], m[0] - c[0])

        def between(a, lo, hi):  # is a on the ccw sweep lo->hi
            return (a - lo) % (2 * math.pi) <= (hi - lo) % (2 * math.pi)
        if between(am, a0, a1):
            a1 = a0 + (a1 - a0) % (2 * math.pi)
        else:
            a1 = a0 - (a0 - a1) % (2 * math.pi)
        return [arc_pts(c, r, a0, a1)]
    if st == pcbnew.SHAPE_T_POLY:
        out = []
        ps = g.GetPolyShape()
        for i in range(ps.OutlineCount()):
            o = ps.Outline(i)
            pts = [xy(o.CPoint(k)) for k in range(o.PointCount())]
            out.append(pts + [pts[0]])
        return out
    return []


lines = []
fronts = [fp for fp in b.GetFootprints() if not fp.IsFlipped()]
for fp in fronts:
    name = fp.GetFPID().GetLibItemName().wx_str()
    if name.startswith('MountingHole'):
        continue
    src = pcbnew.F_Fab if name.startswith('CP_Radial') else pcbnew.F_SilkS
    for g in fp.GraphicalItems():
        if g.GetClass() == 'PCB_SHAPE' and g.GetLayer() == src:
            lines += shape_lines(g)

# USB direction mark for the SuperMini (U3): an arrow along the module's centre line pointing at the USB-C end
# (the pin 1 / pin 9 end of the footprint), so the module can't be fitted the wrong way round.
u3 = b.FindFootprintByReference('U3')
usb_mark = None
if u3 is not None:
    c0 = xy(u3.GetPosition())
    e1, e9 = xy(u3.FindPadByNumber('1').GetPosition()), xy(u3.FindPadByNumber('9').GetPosition())
    mid = ((e1[0] + e9[0]) / 2, (e1[1] + e9[1]) / 2)
    dl = math.hypot(mid[0] - c0[0], mid[1] - c0[1])
    d = ((mid[0] - c0[0]) / dl, (mid[1] - c0[1]) / dl)
    nrm = (-d[1], d[0])
    tip = (c0[0] + d[0] * (dl + 0.5), c0[1] + d[1] * (dl + 0.5))
    tail = (c0[0] + d[0] * (dl - 5.0), c0[1] + d[1] * (dl - 5.0))
    head = [(tip[0] - d[0] * 1.5 + nrm[0] * s_, tip[1] - d[1] * 1.5 + nrm[1] * s_) for s_ in (1.0, -1.0)]
    lines += [[tail, tip], [head[0], tip, head[1]]]
    usb_mark = (c0, d, dl)
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

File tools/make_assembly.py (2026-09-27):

"""Assembly drawings for the milled board, at 2:1 on A4 landscape (SVG + PDF):

  top    - the board as seen from the TOP: every top-side part with reference and value, the pads that need a top
           solder joint (ring, as on the engraved legend) and the vias.
  bottom - the board as seen from the BOTTOM (mirrored left-right): the 1206 SMD parts and the vias; through-hole
           parts in grey for orientation.

Vias are numbered the same way on both drawings (reading order as seen from the bottom).

Usage (KiCad's Python):
    "C:/Program Files/KiCad/10.0/bin/python.exe" tools/make_assembly.py texecom-power-reset.kicad_pcb top    docs/pcb-assembly-top.svg
    "C:/Program Files/KiCad/10.0/bin/python.exe" tools/make_assembly.py texecom-power-reset.kicad_pcb bottom docs/pcb-assembly-bottom.svg
The PDF is printed through headless Edge/Chrome (real fonts); MuPDF is the fallback.
"""
import math
import os
import subprocess
import sys
import tempfile
import pcbnew

PCB, SIDE, OUT = sys.argv[1], sys.argv[2], sys.argv[3]
assert SIDE in ('top', 'bottom')
TOP = SIDE == 'top'
S = 1e6
SC = 2.0                                  # drawing scale (page mm per board mm)
PAGE_W, PAGE_H = 297.0, 210.0             # A4 landscape
OX, OY = 12.0, 30.0                       # board drawing origin on the page

DESC_BOTTOM = {  # what each bottom part does (short, for the parts table)
    'F1': 'PTC fuse 0.5A, battery feed', 'C5': '10µF X5R, timer ch1 (CEXT)', 'C6': '10µF X5R, timer ch2 (CEXT)',
    'R7': '1k, Q1 base (ch1)', 'R8': '1k, Q2 base (ch2)', 'R9': '1k, GPIO4 series (ch1)', 'R10': '1k, GPIO3 series (ch2)',
    'R11': '100Ω, C5 series', 'R12': '100Ω, C6 series', 'R15': '1k, K1 LED', 'R16': '1k, K2 LED',
}
SHORT_VALUE = {'Pololu S9V11E2F5': 'Pololu 5V', 'ESP32-C3 SuperMini': 'ESP32-C3', 'SRD-05VDC': 'SRD-05VDC'}
BLUE, BLUE_T, PINK, ORANGE = '#2f6db5', '#1f4f8a', '#c2185b', '#d9480f'

b = pcbnew.LoadBoard(PCB)
bb = b.GetBoardEdgesBoundingBox()
X0, Y0, X1, Y1 = bb.GetX() / S, bb.GetY() / S, bb.GetRight() / S, bb.GetBottom() / S
CU = pcbnew.F_Cu if TOP else pcbnew.B_Cu


def P(x, y):
    """board mm -> page mm (mirrored left-right for the bottom view)"""
    return (OX + SC * (x - X0) if TOP else OX + SC * (X1 - x)), OY + SC * (y - Y0)


def xy(v):
    return v.x / S, v.y / S


def fmt(v):
    return ('%.3f' % v).rstrip('0').rstrip('.')


def esc(t):
    return t.replace('&', '&amp;').replace('<', '&lt;').replace('>', '&gt;')


def nice_value(v):
    v = v.replace('uF', 'µF').replace('nF', 'nF')
    if v in ('100', '1k', '10k', '100k', '1M') or v.endswith('k') and v[:-1].isdigit():
        v = v if v.endswith(('k', 'M')) else v + 'Ω'
    return SHORT_VALUE.get(v, v)


def poly_path(pts):
    return 'M' + ' L'.join('%s %s' % (fmt(a), fmt(c)) for a, c in (P(*p) for p in pts)) + ' Z'


def sps_path(sps):
    d = []
    for i in range(sps.OutlineCount()):
        o = sps.Outline(i)
        d.append(poly_path([xy(o.CPoint(k)) for k in range(o.PointCount())]))
        for j in range(sps.HoleCount(i)):
            h = sps.Hole(i, j)
            d.append(poly_path([xy(h.CPoint(k)) for k in range(h.PointCount())]))
    return ' '.join(d)


def shape_path(g):
    """F.SilkS / F.Fab graphic -> SVG path (page coords)"""
    st = g.GetShape()
    if st == pcbnew.SHAPE_T_SEGMENT:
        return poly_path([xy(g.GetStart()), xy(g.GetEnd())])[:-2]
    if st == pcbnew.SHAPE_T_RECTANGLE:
        return poly_path([xy(v) for v in g.GetRectCorners()])
    if st == pcbnew.SHAPE_T_CIRCLE:
        cx, cy = P(*xy(g.GetCenter()))
        rr = SC * g.GetRadius() / S
        return 'M%s %s a%s %s 0 1 0 %s 0 a%s %s 0 1 0 %s 0' % (fmt(cx - rr), fmt(cy), fmt(rr), fmt(rr), fmt(2 * rr), fmt(rr), fmt(rr), fmt(-2 * rr))
    if st == pcbnew.SHAPE_T_ARC:
        c = xy(g.GetCenter())
        s_, m_, e_ = xy(g.GetStart()), xy(g.GetArcMid()), xy(g.GetEnd())
        r_ = math.hypot(s_[0] - c[0], s_[1] - c[1])
        a0 = math.atan2(s_[1] - c[1], s_[0] - c[0])
        a1 = math.atan2(e_[1] - c[1], e_[0] - c[0])
        am = math.atan2(m_[1] - c[1], m_[0] - c[0])
        sweep = (a1 - a0) % (2 * math.pi)
        if (am - a0) % (2 * math.pi) > sweep:
            sweep -= 2 * math.pi
        pts = [(c[0] + r_ * math.cos(a0 + sweep * k / 24), c[1] + r_ * math.sin(a0 + sweep * k / 24)) for k in range(25)]
        return poly_path(pts)[:-2]
    if st == pcbnew.SHAPE_T_POLY:
        ps = g.GetPolyShape()
        return ' '.join(poly_path([xy(ps.Outline(i).CPoint(k)) for k in range(ps.Outline(i).PointCount())])
                        for i in range(ps.OutlineCount()))
    return ''


out = []
add = out.append
add('<svg xmlns="http://www.w3.org/2000/svg" width="%smm" height="%smm" viewBox="0 0 %s %s" '
    'font-family="Arial, Helvetica, sans-serif">' % (PAGE_W, PAGE_H, PAGE_W, PAGE_H))
add('<rect x="0" y="0" width="%s" height="%s" fill="#ffffff"/>' % (PAGE_W, PAGE_H))

# ---- title ----
if TOP:
    title = 'Texecom power reset · rev A · top side (component side)'
    sub = ('Viewed from the TOP, as the engraved legend reads. Scale 2:1 (print at 100%, A4 landscape). '
           'Parts sit on this side; most joints are soldered underneath.')
else:
    title = 'Texecom power reset · rev A · bottom side (solder side)'
    sub = ('Viewed from the BOTTOM: the board is flipped left-right, as you see it when soldering. '
           'Scale 2:1 (print at 100%, A4 landscape).')
add('<text x="%s" y="14" font-size="6.2" font-weight="700" fill="#1d2b2f">%s</text>' % (OX, esc(title)))
add('<text x="%s" y="21" font-size="3.4" fill="#4a5a5e">%s</text>' % (OX, esc(sub)))

# ---- board outline (rounded rectangle from Edge.Cuts) ----
r = 0
for d in b.GetDrawings():
    if d.GetLayer() == pcbnew.Edge_Cuts and d.GetShape() == pcbnew.SHAPE_T_ARC:
        r = d.GetRadius() / S
        break
bx = min(P(X0, Y0)[0], P(X1, Y0)[0])
add('<rect x="%s" y="%s" width="%s" height="%s" rx="%s" fill="#f6f4ee" stroke="#1d2b2f" stroke-width="0.5"/>'
    % (fmt(bx), fmt(OY), fmt(SC * (X1 - X0)), fmt(SC * (Y1 - Y0)), fmt(SC * r)))
board_page = (bx, OY, bx + SC * (X1 - X0), OY + SC * (Y1 - Y0))
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

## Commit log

2026-09-25 Switch to on-board relays and add wired schematic
    - Replace the off-board REL-2CHAN-335V relay module with two on-board
    SRD-05VDC-SL-C relays, 2N2222A drivers, 1N4007 flyback diodes and red
    indicator LEDs; remove J5-J7, the control lead and the Q/nQ links
    - Redraw the schematic with wires (power symbols only for GND/+5V),
    ERC clean and netlist verified net by net
    - Use a 74HCT4538 at 5V for the hardware timeout, with 1k GPIO series
    resistors and 100R CEXT power-down protection
    - Update README (requirements, design, bench tests, decisions) and BOM
    (Micro Robotics / Communica sourcing with stock status)
    - Keep earlier schematic versions in backup/ for reference
    - Add .gitignore and .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
    [texecom-power-reset.kicad_sch, texecom-power-reset_module-version.kicad_sch]
2026-09-25 Add PCB rev A, milling footprints, fab files and project summary
    - PCB rev A (92 x 70 mm, 2-layer, CNC-milled): placed and routed with the
    KiCad routing tools at 0.8 mm clearance, 15 wire-link vias, GND pours;
    DRC 0 violations / 0 unconnected, connectivity verified against schematic
    - Milling footprint variants (oval enlarged pads; per-pad top keepouts on
    parts whose body covers the top pads) and custom .kicad_dru rules
    - Schematic footprints assigned to the milling variants
    - Gerbers (F.Cu, B.Cu, Edge.Cuts) and Excellon drill in fab/
    - Copper renders and assembly drawing in docs/
    - project-summary.html: one-page visual summary, linked from the README
    - README: PCB section, drill table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
    [texecom-power-reset.kicad_pcb, texecom-power-reset.kicad_sch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]
2026-09-25 Add KiCad 3D renders to the project summary
2026-09-25 Remove top GND pour and add engraved Mill_Legend layer
    - GND poured on the bottom layer only; three GND pads rejoined with
    short bottom tracks and one extra via (16 vias total)
    - New Mill_Legend layer (User.1): part outlines, polarity marks,
    references and BAT IN / BAT OUT / AC IN / AC OUT labels, kept 0.35mm
    clear of all top copper; exported as fab/*-Mill_Legend.gbr
    - tools/make_legend.py regenerates the legend after layout changes
    - Regenerated fab/ Gerbers and drill, docs/ renders
    - README and project summary updated
    [texecom-power-reset.kicad_pcb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]
2026-09-25 Mark top-joint pads on the legend and add solder-top table
    - Engraved ring beside each of the 20 pads that carry a top track,
    with a "o = SOLDER TOP" key; each ring is clearly nearest its pad
    - README assembly step 3: table of axial/disc parts and the pads
    that must be soldered on top
    - Regenerated legend Gerber, top copper SVG, assembly PDF and summary
    [texecom-power-reset.kicad_pcb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]
2026-09-25 Correct mirrored SuperMini footprint; rotate U3, swap GPIO3/GPIO4
    - ESP32-C3-SuperMini footprints: pin rows were mirrored (matched the
    bottom-view pinout drawing); corrected so the module mounts button
    side up
    - U3 rotated 180 deg: USB-C at the board edge, original routing kept
    (DRC 0/0, 16 vias); antenna keepout removed
    - Schematic: GPIO4 -> channel 1 (K1 battery), GPIO3 -> channel 2 (K2 AC)
    - Legend: "USB ->" arrow on U3
    - BOM: optional Communica IPEX WiFi antenna
    - README (Tasmota GPIO table, V2 WS2812 on GPIO8, orientation,
    decisions), regenerated fab/, docs/, schematic PDF and summary
    [texecom-power-reset.kicad_pcb, texecom-power-reset.kicad_sch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]
2026-09-25 BOM: Micro Robotics U.FL antenna as the optional WiFi antenna
    - BAT-P60-WIFI-2 (flexible PCB, U.FL on 100mm lead) as the main choice,
    Communica 4dBi enclosed antenna kept as the alternative
    - README antenna note points to it
2026-09-25 README: milling order and FlatCAM steps for the legend engrave
2026-09-25 Project summary: milling order and FlatCAM legend engrave panels
2026-09-25 README: commercial alternative (ESP8266 2 x 30A relay board)
2026-09-26 FlatCAM project and G-code (isolation, legend, drills, alignment)
    - flatcam/CNC: B.Cu and F.Cu isolation, Mill_Legend follow engrave,
    drills (0.8, 1.0 incl. 0.9, 1.5 incl. 1.3, 3.2) and alignment drills
    - Updated FlatCAM project
2026-09-26 FlatCAM: board outline cutout G-code, updated project
2026-09-26 Milling order: outline on double-sided tape; add kicad-output export
    - README and project summary: board outline cut without tabs, board
    held on double-sided tape
    - kicad-output/: user's KiCad plot (Gerbers incl. Mill_Legend, PTH/NPTH
    drills, zip); fab/fab.zip; KiCad plot settings
    [texecom-power-reset-B_Cu.gbr, texecom-power-reset-B_Mask.gbr, texecom-power-reset-B_Paste.gbr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]
2026-09-27 Drilling guidance: fishtail alignment holes and drill feeds at 12,000rpm
    - README and project summary: 2.4mm fishtail alignment holes
    (100-150mm/min, 1mm steps) and per-size Z feeds for the hole drills
    - flatcam/CNC: v2 drill G-code with per-size feeds (75/100/130/100)
    - Remove fab/fab.zip (stale copy of fab/)
2026-09-27 Remove superseded drill G-code (v2 files with per-size feeds replace them)
2026-09-27 Top and bottom assembly drawings (2:1, A4 landscape)
    - tools/make_assembly.py: generates both views (SVG + PDF via headless
    browser); vias numbered the same on both
    - Top: every part with ref and value, polarity marks, the 20 top-joint
    pads ringed; bottom: mirrored view, 1206 parts labelled, vias numbered
    - README assembly notes and project summary show both drawings; replaces
    the old F.Fab-only pcb-assembly-top.pdf
    [make_assembly.py]
2026-09-27 Milling: 4 isolation passes on both copper layers
    - README and project summary: why one pass left thin top gaps and bottom
    copper slivers, the 4-pass / 15-20% overlap settings, and checking a
    milled board for slivers and shorts
